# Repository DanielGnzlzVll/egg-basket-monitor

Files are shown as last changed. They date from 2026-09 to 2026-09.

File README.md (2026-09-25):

# Egg Basket Monitor

Sensor de nivel para una canasta de huevos de cocina. Se cuelga del borde,
mide la distancia hasta los huevos con un sensor de tiempo de vuelo
(**VL53L0X**, módulo TOF200C), duerme casi todo el tiempo en un **ESP32-C3
SuperMini** a batería y manda una lectura por hora a **Grafana Cloud**.

El objetivo no es contar huevos, sino avisar con tiempo antes de quedarse en
cero, y hacerlo:

- **sin volcar ni modificar la canasta** — todo cuelga del borde con piezas
  impresas;
- **sin PCB a medida** — módulos comerciales y cables Dupont;
- **sin infraestructura en casa** — el dispositivo habla directo con Grafana
  Cloud, sin broker MQTT ni servidor intermedio;
- **sin credenciales en el código** — WiFi y token se cargan desde un portal
  web que sirve el propio dispositivo.

## Cómo funciona

```
 ┌──────────── deep sleep (60 min por defecto) ◄──────────────┐
 ▼                                                            │
despierta → 20 lecturas ToF → mediana + desviación → batería → WiFi → POST HTTPS
            (sensor encendido     (descarta las        (GPIO3)         a Grafana Cloud
             sólo ~1 s)            inválidas)                          (Influx line protocol)
```

El sensor cuelga de un lado corto de la canasta y apunta **en diagonal** hacia
el fondo, para no tapar la boca. El ángulo se ajusta a mano con una bisagra de
fricción, usando el [modo calibración](docs/calibration.md) para verlo en
vivo. Cuantos más huevos hay, más corta es la distancia medida.

Cada envío es una línea de
[Influx line protocol](https://docs.influxdata.com/influxdb/v2/reference/syntax/line-protocol/):

```
eggbasket,device=cocina distance_mm=412,stddev=1.8,valid=19,status=0,battery_mv=4050,rssi=-52,boots=412
```

| Campo | Qué es |
|---|---|
| `distance_mm` | Mediana de las lecturas válidas del ciclo |
| `stddev` | Desviación estándar de esas lecturas. Si sube de forma sostenida, el ángulo se corrió |
| `valid` | Cuántas de las 20 lecturas fueron válidas |
| `status` | `0` = lectura del ciclo · `1` = lectura reenviada desde el buffer de reintento · `2` = el sensor falló (esa línea no lleva `distance_mm` ni `stddev`) |
| `battery_mv` | Tensión de la celda, leída por el divisor en GPIO3 |
| `rssi` | Señal WiFi en dBm |
| `boots` | Contador de despertares desde el último reset |

Si el envío falla (sin WiFi, error de conexión o del servidor), la muestra
se guarda en la memoria RTC, que sobrevive al deep sleep, con la hora real en
que se midió. En el siguiente envío que funcione se mandan **todas** las
pendientes junto con la actual, en un solo POST y cada una con su hora: un
router reiniciándose no deja huecos en los datos. Entran 48 muestras (dos
días enviando cada hora); si se llena, se descarta la más vieja. Si Grafana
rechaza los datos en sí (HTTP 400, por ejemplo una muestra demasiado vieja),
se descartan en vez de reintentarlos para siempre. El log por serial muestra
las líneas exactas de cada envío. La
calibración distancia → nivel de llenado no vive en el firmware sino en
Grafana, para poder recalibrar sin reflashear.

## Hardware

| Componente | Para qué | Nota |
|---|---|---|
| ESP32-C3 SuperMini | Microcontrolador, WiFi | Número serigrafiado = número de GPIO |
| Módulo ToF **TOF200C (VL53L0X)** | Mide la distancia | **VIN a 3V3, no a 5V.** Ver [abajo](#el-sensor-vl53l0x-no-vl53l1x) |
| TP4056 **con protección** (DW01A + FS8205A), USB-C | Carga la celda y la corta por sobre/subdescarga | La versión sin protección no sirve con una celda desnuda |
| Celda 18650 | Batería, ~4 meses por carga | Nada se suelda a la celda |
| 2 resistencias iguales (1 MΩ) | Divisor para leer la batería | Cualquier par igual sirve |
| Tornillería M3 + M2 con tuercas | Montaje | Sin un solo autorroscante |

Todo por ~USD 8-12 si ya tenés la placa y la celda. Lista completa, con
búsquedas de AliExpress y largos de tornillo, en [`docs/bom.md`](docs/bom.md).

### Conexionado

Esquema de conexionado

| Señal | ESP32-C3 SuperMini | TOF200C |
|---|---|---|
| SDA (I2C) | GPIO4 | SDA |
| SCL (I2C) | GPIO5 | SCL |
| XSHUT (apagado del sensor) | GPIO6 | SHUT |
| Alimentación | 3V3 / GND | VIN / GND |
| Lectura de batería | GPIO3 ← punto medio del divisor | — |

El I2C va en GPIO4/5 y no en los pines por defecto del C3 porque GPIO8 es el
LED RGB de la placa y GPIO9 el botón BOOT.

Cadena de alimentación

Tabla de pines completa, detalles del divisor y el riesgo abierto del
regulador de la placa en [`docs/wiring.md`](docs/wiring.md).

### El sensor: VL53L0X, no VL53L1X

El diseño original pedía un VL53L1X, pero el módulo instalado es un
**TOF200C**, que lleva un **VL53L0X**. Los dos se parecen mucho y contestan
en la misma dirección I2C (`0x29`), así que un escaneo del bus no los
distingue, pero sus registros son incompatibles: el VL53L0X usa direcciones
de 8 bits y el VL53L1X de 16. Con la librería equivocada el escaneo encuentra
el sensor y aun así la inicialización falla siempre. El firmware usa
`pololu/VL53L0X`.

| | VL53L0X (TOF200C, instalado) | VL53L1X (TOF400C) |
|---|---|---|
| Alcance en interior | ~1.2 m (hasta ~2 m con poca luz) | hasta 4 m |
| Cono de visión | 25°, fijo | 27°, reducible con ROI hasta ~15° |
| Identificación | registro `0xC0` = `0xEE` | registro `0x010F` = `0xEACC` |
| Librería | `pololu/VL53L0X` | `pololu/VL53L1X` |

Para una canasta de 50 cm el alcance sobra. La limitación es el cono: sin ROI
no se puede estrechar, y si toca las paredes de la canasta las lecturas salen
más cortas que la distancia real a los huevos. Si pasa, la salida es un
TOF400C, que se conecta igual.

## Piezas impresas

Cinco piezas en PETG (no PLA: la cocina tiene calor y grasa), ninguna
necesita soportes. Toda la tornillería es métrica contra tuerca embutida.

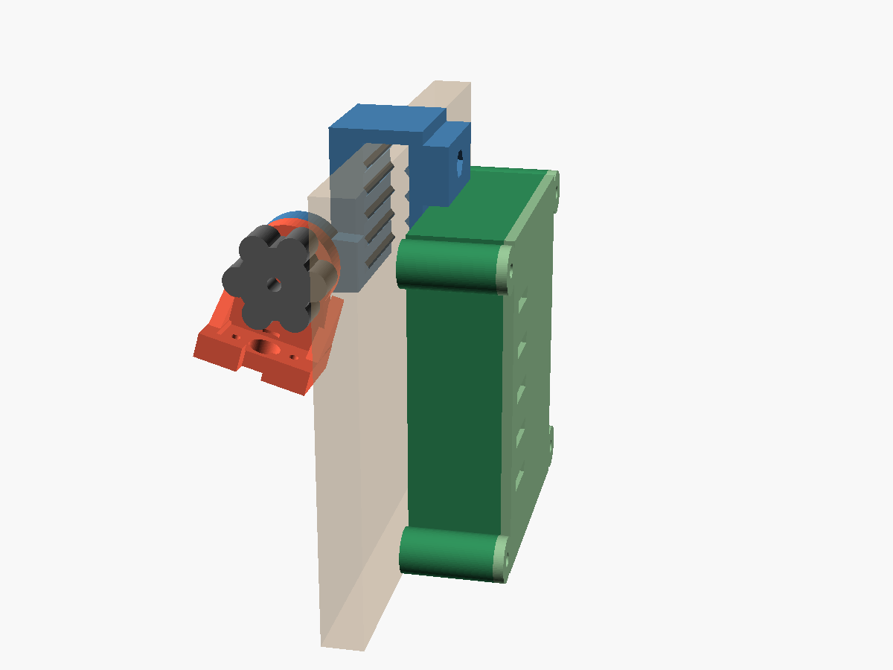
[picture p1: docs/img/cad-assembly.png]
Conjunto colgado del borde de la canasta


*Conjunto colgado del borde (vista aproximada): la cabeza del sensor hacia
dentro de la canasta y la caja de electrónica por fuera, sujetas por el mismo
`mount`; el peso de la caja compensa el brazo del sensor.*

| | |
|---|---|
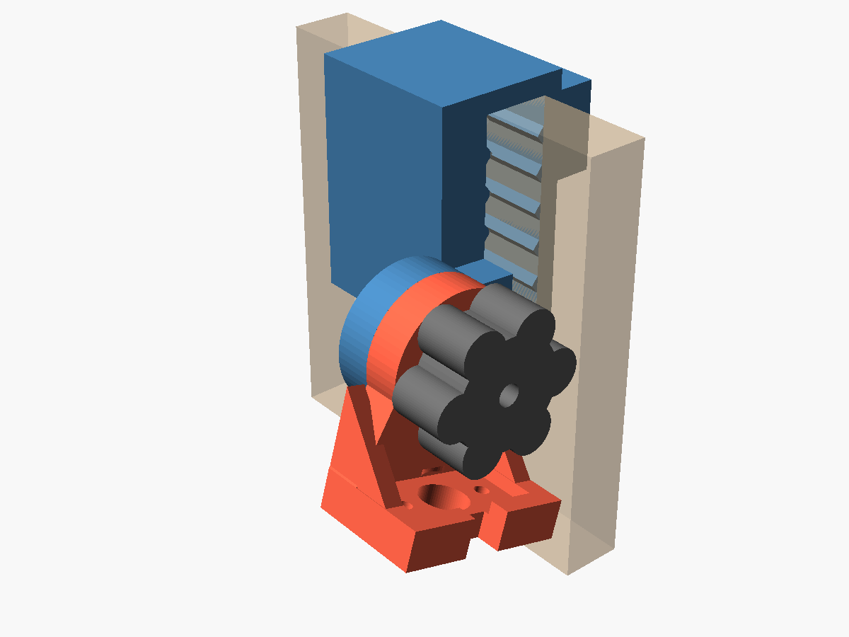
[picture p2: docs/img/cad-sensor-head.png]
Cabeza del sensor
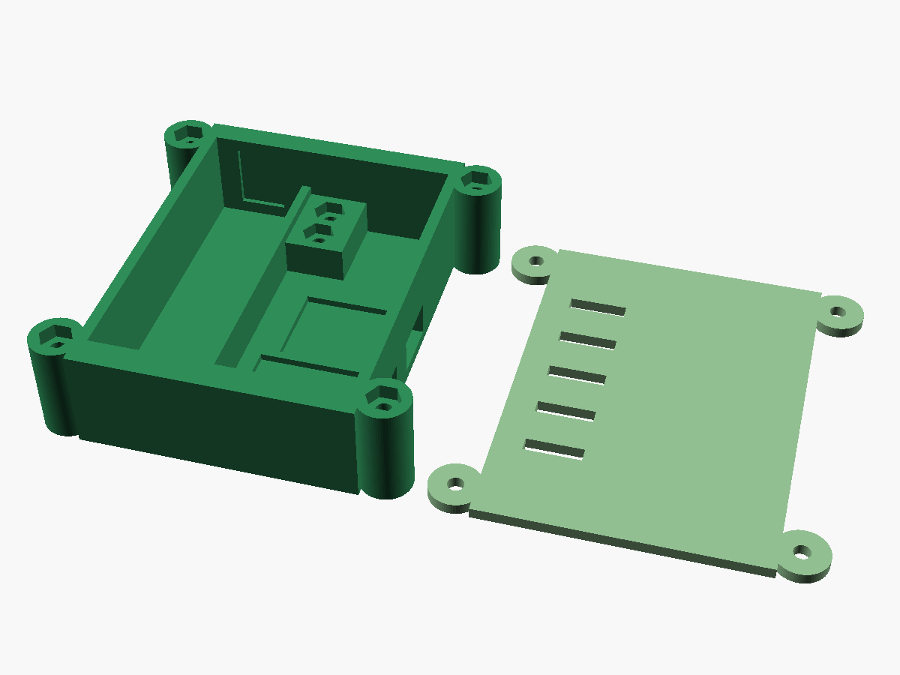
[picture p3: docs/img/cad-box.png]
Caja de electrónica
|  |  |
| **Cabeza del sensor**: `mount` al borde (azul) + `pod` con el bolsillo del TOF200C (rojo) + `knob` de la bisagra de fricción (gris) | **Caja de electrónica**: hueco de la 18650, marcos del TP4056 y el ESP32-C3, espina con las tuercas para el `mount` y la `lid` al lado |

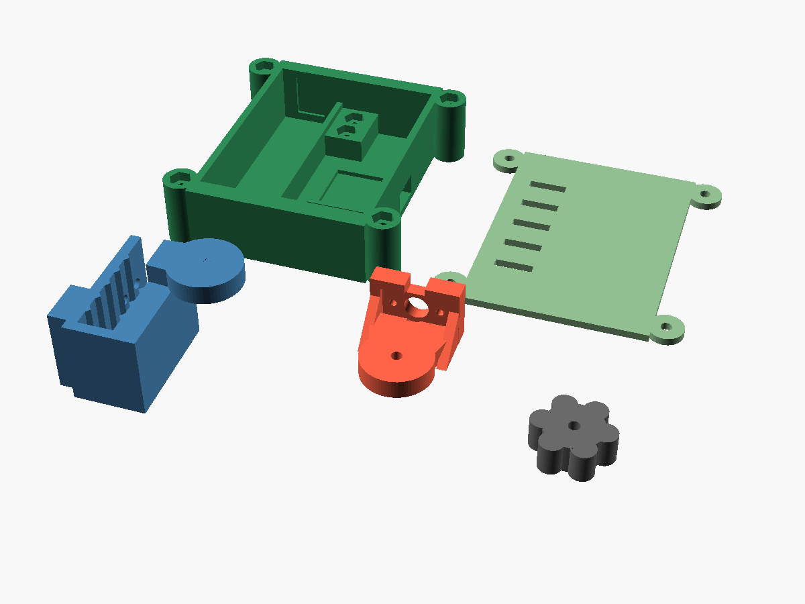
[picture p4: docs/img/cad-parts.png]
Las cinco piezas imprimibles


| Pieza | Qué es | Orientación de impresión |
|---|---|---|
| `mount` | Gancho al borde con un solo punto de apriete, sostiene el pod | De canto |
| `pod` | Alojamiento del TOF200C con la oreja de la bisagra | Oreja hacia arriba |
| `knob` | Pomo de apriete de la bisagra de fricción | Plana |
| `box` | Caja de la electrónica | Boca hacia arriba |
| `lid` | Tapa de la caja | Plana |

Los STL se generan con OpenSCAD:

```
python cad/build.py                 # las cinco piezas, a cad/out/
python cad/build.py pod knob        # sólo esas
python cad/build.py --report        # informe de geometría y tornillería, sin STL
```

Todas las cotas (medidas de la canasta, cono del sensor, tornillería) están
en [`cad/params.scad`](cad/params.scad). `cad/lib/geometry.scad` calcula el
rango de ángulos en el que el cono del sensor llega al fondo sin tocar las
paredes, y aborta la compilación si la canasta no deja ninguno.

**Impresión:** PETG, capa 0.2 mm, 4 perímetros, sin soportes.

## Puesta en marcha

1. **Imprimir y montar** las piezas (arriba) y cablear según el
   [esquema](docs/wiring.md).
2. **Flashear** con [PlatformIO](https://platformio.org/):
   ```
   cd firmware
   pio run -t upload
   pio device monitor      # opcional, para ver los logs
   ```
3. **Configurar.** Recién flasheado, el dispositivo levanta la red WiFi
   **`EggBasket-Setup`** (contraseña `eggbasket2026`, cambiala en
   `firmware/include/config.h` antes de flashear). Conectate desde el celular
   y cargá tu WiFi, la URL de escritura Influx de Grafana Cloud, el Instance
   ID, el token, el nombre del dispositivo y el intervalo de sueño.
4. **Calibrar el ángulo** con la canasta vacía, usando el
   [modo calibración](docs/calibration.md).
5. **Verificar** en Grafana Cloud → Explore → `eggbasket_distance_mm`.

Paso a paso completo, con capturas de lo que sale por serial y qué hacer si
algo falla, en [`docs/setup-tutorial.md`](docs/setup-tutorial.md).

### Botón BOOT y LED

El único botón es el BOOT de la placa. Sostenido **al arrancar** (reset o
conexión de la batería) decide el modo:

| BOOT al arrancar | Modo | LED |
|---|---|---|
| Sin tocar | Ciclo normal: mide, envía, duerme | Verde corto = envío OK · rojo corto = falló, queda para reintentar |
| Sin tocar, **con monitor serie abierto por USB** | Calibración automática | Dos parpadeos verdes |
| 3-8 s | Calibración: 60 s de distancia cruda por serial a 2 Hz | Dos parpadeos verdes |
| Más de 8 s | Portal de configuración `EggBasket-Setup` | Tres parpadeos azules y queda azul fijo |

La calibración automática sólo mira si hay una PC leyendo el puerto serie:
en batería no cuesta nada. Para ver el ciclo normal por serial, poner
`AUTO_CALIBRATION_ON_SERIAL` a `0` en `firmware/include/config.h`.

Tres parpadeos rojos significan batería por debajo de 3.3 V: el dispositivo
entra en sueño indefinido para proteger la celda hasta que se la cargue.

## Autonomía

Con una 18650 de 3000 mAh (2400 mAh utilizables) y un envío por hora:

| Concepto | mAh/día |
|---|---|
| Deep sleep del C3 SuperMini de fábrica (~500 µA) | 12.0 |
| 24 despertares × ~6 s @ ~80 mA | 3.2 |
| TP4056 en reposo + divisor de batería | 1.3 |
| Sensor con XSHUT bajo | ~0.1 * |
| **Total** | **~16.6** |

Unos **4 meses entre cargas**, contando la autodescarga de la celda. El ~90%
del consumo dormido es el LED rojo de power del SuperMini: raspándolo o
desoldándolo, la autonomía sube a **~8.5 meses**. Bajar a dos envíos por día
apenas suma un mes, porque el sueño domina.

\* Calculado para el VL53L1X. El TOF200C trae su propio regulador, cuyo
consumo en reposo no está medido todavía: si resulta alto, ver el plan B
(load switch) en [`docs/bom.md`](docs/bom.md).

## Grafana Cloud

Los datos entran por el endpoint Influx de Grafana Cloud y quedan como series
Prometheus (`eggbasket_distance_mm`, `eggbasket_battery_mv`, …) con el label
`device`. Lo planificado, todavía **pendiente** en el repo:

- **Dashboard** con variables `d_vacia` y `d_llena` para convertir distancia
  en nivel de llenado, más paneles de batería, `stddev`/`valid` y RSSI.
- **Dos alertas a Telegram:** nivel por debajo del 25% durante 2 h
  ("quedan pocos huevos"), y **sin datos durante 36 h** ("el sensor no
  reporta"). La segunda importa tanto como la primera: sin ella, una batería
  agotada es indistinguible de una canasta llena.

El detalle está en la sección "Grafana Cloud" del
[spec de diseño](docs/superpowers/specs/2026-09-04-egg-basket-monitor-design.md).

## Estado del proyecto

- **Firmware:** compila con PlatformIO para el ESP32-C3. El sensor TOF200C
  está verificado en banco, midiendo con el driver del VL53L0X. Falta
  probar el ciclo completo (sensor + WiFi + Grafana) en la placa.
- **CAD:** rediseñado para el TOF200C, con rim mount y bisagra de fricción.
- **Grafana:** dashboard y alertas pendientes.
- **Riesgos abiertos:**
  - El regulador del SuperMini: si es un AMS1117 en vez de uno de baja
    caída, la placa se apaga por debajo de ~4.4 V, con la celda casi llena.
    Se verifica con una fuente variable; ver [`docs/wiring.md`](docs/wiring.md).
  - El cono fijo del VL53L0X contra las paredes de la canasta (ver
    [el sensor](#el-sensor-vl53l0x-no-vl53l1x)).

## Estructura del repo

```
firmware/       Proyecto PlatformIO (ESP32-C3 SuperMini, framework Arduino)
  include/        config.h: pines, tiempos y valores por defecto
  src/            main.cpp (ciclo), sensor, power, telemetry, portal, settings, boot_mode
cad/            Piezas paramétricas en OpenSCAD + build.py para exportar STL
  lib/            Geometría del cono del sensor y gancho al borde
docs/           Cableado, tutorial, calibración, lista de materiales, imágenes
  superpowers/    Specs de diseño y planes de implementación
```

## Documentación

| Documento | Contenido |
|---|---|
| [`docs/setup-tutorial.md`](docs/setup-tutorial.md) | Flasheo, portal de configuración, verificación y problemas comunes |
| [`docs/wiring.md`](docs/wiring.md) | Pinout completo, cadena de alimentación, sensor, botón BOOT |
| [`docs/calibration.md`](docs/calibration.md) | Cómo elegir el ángulo del sensor con el modo calibración |
| [`docs/bom.md`](docs/bom.md) | Lista de materiales, tornillería y piezas impresas |
| [Spec de diseño](docs/superpowers/specs/2026-09-04-egg-basket-monitor-design.md) | Por qué cada decisión, alternativas descartadas, presupuesto energético |
| [Spec del portal WiFi](docs/superpowers/specs/2026-09-17-firmware-wifi-config-design.md) | Provisioning por portal cautivo y guardado en NVS |
| [Spec del rim mount](docs/superpowers/specs/2026-09-18-cad-rim-mount-redesign-design.md) | Rediseño del montaje al borde y bisagra de fricción |

## Licencia

[MIT](LICENSE).

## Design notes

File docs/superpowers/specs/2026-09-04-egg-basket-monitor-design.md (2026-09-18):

# Egg Basket Monitor — Diseño

**Fecha:** 2026-09-04
**Estado:** aprobado, pendiente de plan de implementación

## Problema

Los huevos se acaban sin aviso. Para cuando se nota, ya no hay, y la compra se
pospone otro día. El objetivo es recibir una notificación en Telegram cuando el
nivel de la canasta baje de un umbral, con suficiente antelación para comprar
antes de quedarse en cero.

Requisito secundario, y casi tan importante: el sistema debe avisar cuando *él
mismo* deja de funcionar. Una batería agotada produce exactamente el mismo
silencio que una canasta llena.

## Alcance

Dentro:

- Sensor de nivel montado en la canasta, alimentado por batería.
- Envío periódico a Grafana Cloud sin infraestructura intermedia.
- Dashboard y dos reglas de alerta con notificación a Telegram.
- Piezas imprimibles paramétricas para el sensor y la electrónica.

Fuera:

- PCB a medida. Todo se resuelve con módulos comerciales y cables Dupont.
- Conteo exacto de huevos. Se estima nivel de llenado, no unidades.
- Integración con Home Assistant, listas de compra o pedidos automáticos.
- Multi-canasta. Un solo dispositivo, aunque el esquema de métricas lleva un
  label `device` que lo permitiría después.

## Decisiones de diseño

### Sensado: ToF de zona única

Se evaluaron cuatro alternativas:

| Opción | Descartada porque |
|---|---|
| Barrera IR × 5 niveles | 10 piezas a alinear en una canasta curva, ~10 GPIO, y el haz se cuela entre huevos produciendo falsos vacíos. |
| Sensores de luz ambiente × 5 | Dependen de la iluminación de la cocina, la hora del día y la posición de la canasta. |
| Celda de carga (HX711) | Da conteo real, pero obliga a que la canasta se apoye en una plataforma y sufre deriva del cero a largo plazo. |
| **ToF (elegida)** | Un sensor, un bus, montaje simple, medición independiente de la luz ambiente. |

Dentro de ToF se eligió **VL53L1X** (zona única) sobre VL53L5CX/L8CX (8×8
multizona). El multizona sería técnicamente superior para el montaje diagonal
—devuelve un mapa de profundidad de 64 zonas con 65° de FoV, inmune a los huecos
entre huevos— pero cuesta 3-5× más y es más difícil de conseguir. Se acepta
conscientemente el riesgo de lecturas ruidosas.

**Mitigaciones del ruido, dado que el VL53L1X es un rayo único en diagonal:**

1. 20 lecturas por despertar, se reporta la mediana y la desviación estándar.
   La desviación es un dato de diagnóstico de primera clase: si es alta, el
   ángulo está mal.
2. ROI del receptor reducido para estrechar el cono. El emisor siempre dispara
   27° y eso no es configurable; solo el receptor admite ROI, hasta un mínimo
   de 15° con 4×4 SPADs.
3. Articulación con detentes cada 4° en la pieza impresa, para corregir el
   ángulo sin reimprimir. El ángulo es el parámetro que más probablemente falle
   a la primera. El rango realmente utilizable lo fija la geometría de la
   canasta, no una preferencia: ver la sección siguiente.

### El cono del emisor decide dónde se monta y a cuánto se apunta

Con las medidas reales de la canasta —**300 mm de ancho × 150 mm de fondo ×
500 mm de alto**, borde de ~10 mm— el apuntado deja de ser libre. La canasta es
un pozo profundo y estrecho, y el emisor del VL53L1X dispara un cono fijo de 27°
que no se puede estrechar. Si el cono toca una pared antes de llegar al fondo, la
pared devuelve más señal que los huevos y el sensor mide la pared.

Dos consecuencias, ambas calculadas en `cad/lib/geometry.scad` a partir de las
tres medidas:

- **La mordaza va en mitad de un lado corto**, apuntando a través de los 300 mm.
  Apuntando a través de los 150 mm no hay **ningún** ángulo válido.
- **El rango útil es 8-20°** desde la vertical, cuatro posiciones de detente.
  Por debajo, el borde cercano del ROI ve la pared de montaje; por encima, el
  borde lejano alcanza la pared de enfrente.

El cálculo parte de la posición **real** del sensor, no del borde de la canasta:
el pod cuelga de un brazo que lo mete ~68 mm hacia dentro y ~70 mm hacia abajo.
Eso lo aleja de la pared de montaje, que ayuda, pero lo acerca a la de enfrente,
que es lo que de verdad recorta el rango por arriba. Hacer el cálculo desde el
borde da un máximo de 23,5° que en la práctica no existe.

En el detente nominal de 16° el sensor lee **450 mm con la canasta vacía y
345 mm llena**, unos 104 mm de recorrido útil. Ambas cifras caen dentro del modo
**short** del VL53L1X, que es el más inmune a la luz ambiente: un resultado
afortunado que conviene no perder al tocar cotas.

`geometry.scad` **aborta la compilación** si no queda ningún ángulo válido, o si
queda solo uno (una articulación con una sola posición no regula nada). Cambiar
las medidas de la canasta a algo imposible falla en voz alta en vez de producir
una pieza inútil.

### Montaje: cabeza en el borde, midiendo en diagonal

El sensor se sujeta al borde de la canasta y apunta en diagonal hacia el fondo
opuesto, no verticalmente desde arriba. Esto deja libre la boca de la canasta,
que es por donde se ponen y sacan los huevos.

El sistema se parte en dos cuerpos unidos por un latiguillo Dupont de 20 cm:

- **Cabeza del sensor** (~35 g): mordaza + placa + pod articulado + VL53L1X.
  Cuelga del borde hacia **dentro**.
- **Caja de electrónica** (~90 g con la celda): MCU, 18650, TP4056. Cuelga del
  borde hacia **fuera**, con su propio gancho.

**Corrección respecto a la primera versión de este spec.** Antes decía que la
electrónica no podía ir en el borde porque un 18650 con su cuna pesa ~70 g y
volcaría una canasta liviana. Ese razonamiento medía el peso, que es la
magnitud equivocada: lo que vuelca una canasta es el **momento**, y el momento
depende de dónde cuelga la masa. Colgada por fuera, pegada a la pared, la caja
tiene un brazo de ~12 mm; la cabeza del sensor tiene 45 mm hacia el otro lado.
Los dos momentos son del mismo orden y de signo contrario, así que la caja no
solo no empeora el equilibrio: lo mejora. Un cuerpo suelto en la mesa, además,
obligaba a un latiguillo tenso que es justo lo que tira de la canasta.

Se mantienen los dos motivos por los que la caja no va **dentro**: la celda de
litio no queda suspendida sobre la comida, y la canasta se puede levantar y
lavar soltando dos ganchos. La cara inferior de la caja es plana a propósito,
así que también se sostiene de pie en la mesa si se prefiere.

### La calibración vive en Grafana, no en el firmware

El firmware envía **milímetros crudos**. El mapeo distancia → nivel de huevos se
hace en la query del dashboard con dos variables, `d_vacia` y `d_llena`:

```
nivel_pct = (d_vacia - d) / (d_vacia - d_llena) * 100
```

Recalibrar es editar una variable en el navegador. La alternativa —umbrales en
el firmware— exigiría desmontar la canasta y reflashear cada vez, que es
exactamente lo que va a pasar varias veces durante las primeras semanas.

### Telemetría: POST Influx directo a Grafana Cloud

Grafana Cloud acepta Influx line protocol por HTTP: se toma el endpoint de
Prometheus remote-write y se cambia la ruta a `/api/v1/push/influx/write`
(en algunas regiones el host también cambia `prometheus` por `influx`).
Autenticación Basic con el instance ID como usuario y un token de Access Policy
como contraseña; cuerpo `text/plain`.

Es un POST de una línea de texto. Se descartaron:

- **Prometheus remote_write directo**: requiere protobuf + snappy en el ESP32.
  Mucho código y RAM para el mismo resultado.
- **MQTT → Alloy → Cloud**: exige un equipo siempre encendido en casa.

### Cadencia: 1 envío por hora

El requisito original era 1-2 veces al día. Se sube a una vez por hora porque:

1. **Grafana Cloud es Mimir/Prometheus y una muestra caduca a los 5 minutos.**
   Con 2 muestras al día los paneles y alertas verían "No Data" casi siempre.
   Se resuelve igualmente envolviendo las queries en `last_over_time(...[36h])`,
   pero con datos horarios los dashboards son legibles de verdad.
2. Permite ver *cuándo* se consumen los huevos, no solo cuántos quedan.
3. El costo en batería es aceptable (ver presupuesto energético).

El intervalo es una constante del firmware, fácil de cambiar.

## Hardware

### Plataforma: ESP32-C3 SuperMini

Elegida porque el usuario ya tiene varias unidades y una celda 18650. Las
alternativas evaluadas (FireBeetle 2 ESP32-E con deep sleep de 13 µA y carga
LiPo integrada; FireBeetle 2 ESP32-C6) se descartaron por no aportar nada que
justifique comprar hardware nuevo.

Consecuencias de esta elección, todas resueltas abajo: no tiene cargador de
litio, no tiene divisor de batería, y su deep sleep de fábrica es 30-50× peor
que el de una placa pensada para batería.

### Lista de compras

Ya disponible (costo 0): ESP32-C3 SuperMini, celda 18650, resorte de bolígrafo,
lámina de latón o clip metálico, cable USB-C, filamento PETG.

| # | Componente | Búsqueda en AliExpress | USD |
|---|---|---|---|
| 1 | Módulo VL53L1X, versión 3.3 V pequeña | `VL53L1X module GY-53L1` | 3-6 |
| 2 | TP4056 **con protección**, USB-C | `TP4056 USB-C protection DW01` | 0.60 |
| 3 | Resistencias 1 MΩ 1% (×2) | `1M ohm 1% resistor` | 0.20 |
| 4 | Dupont hembra-hembra 20 cm (pack 40) | `dupont female female 20cm` | 1-2 |
| 5 | Termorretráctil surtido | `heat shrink tube assortment` | 1 |
| 6 | Tornillería M3 + M2 | `M3 hex socket screw assortment kit` | 2-3 |
| | **Total** | | **~8-12** |

La lista completa, con las longitudes exactas de tornillo que calcula el modelo,
vive en `docs/bom.md`. Tres ítems de la primera versión han caído: los **imanes
de neodimio** (la caja ya cuelga del borde con su propio gancho), los
**autorroscantes** (ver abajo) y la **miniprotoboard** (no cabe en el vano de
32 mm, y las dos resistencias del divisor se sueldan en línea sobre un Dupont).

### Tornillería: métrica normal en todas partes

Restricción del usuario, y de las que cambian geometría: tiene M2/M3/M4 de
métrica normal a millares, y **ningún autorroscante**. Así que en el proyecto
no hay ni uno. Donde el tornillo no encuentra nada al otro lado, se embute una
tuerca hexagonal en la pieza impresa y es ella la que hace de rosca; el
hexágono a medida impide que gire, y la pieza pasa a comportarse como si
llevara un inserto roscado.

Sale ganando el diseño, no solo la lista de la compra: una rosca hecha en PLA
se pasa a la tercera o cuarta vez que la aprietas, y estas tres uniones —tapa
de la caja, apriete de los ganchos, módulo del sensor— son justo las que se
van a abrir y cerrar muchas veces durante el montaje y la calibración.

Los tres sitios afectados y lo que costó cada uno:

- **Apriete de los dos ganchos** (`lib/rim_hook.scad`). Tuerca cautiva en la
  cara exterior del saliente. Cambio barato: el saliente ya medía 6 mm.
- **Módulo VL53L1X al pod** (`sensor_head.scad`). El agujero pasa de piloto
  Ø2,1 a pasante Ø2,3 y la tuerca M2 va suelta por detrás del PCB, que es
  también lo que lo aprieta contra el fondo del bolsillo.
- **Tapa de la caja** (`electronics_box.scad`). El caro. Ver abajo.

**Nota sobre el ítem 1:** hay que pedir explícitamente la versión pequeña de
3.3 V. Si el módulo trae un regulador AMS1117 (Iq ~5 mA), consume por sí solo
50× más que todo el resto del circuito en reposo y la batería dura semanas en
vez de meses. Plan B si llega el módulo equivocado: un load switch con MOSFET-P
(~USD 1) para cortarle la alimentación entera durante el sueño.

### Conexionado

Se evitan los pines I²C por defecto del C3 SuperMini: GPIO8 lleva el LED RGB y
es strapping pin, y GPIO9 es el botón BOOT. El ESP32-C3 tiene matriz GPIO libre,
así que I²C se remapea.

| Señal | Pin C3 | Va a |
|---|---|---|
| SDA | GPIO4 | VL53L1X SDA |
| SCL | GPIO5 | VL53L1X SCL |
| XSHUT | GPIO6 | VL53L1X XSHUT (bajo = standby ~5 µA) |
| ADC batería | GPIO3 | Nodo medio del divisor 1M/1M |
| Botón calibración | GPIO9 | Botón BOOT de la placa (pull-up interno) |
| 3V3 / GND | — | VL53L1X VCC / GND |

Cadena de alimentación:

```
18650 → TP4056 (B+/B-)
TP4056 (OUT+/OUT-) → pin 5V del C3 SuperMini → LDO onboard → 3V3
                   → divisor 1M/1M → GPIO3
```

**Riesgo abierto que hay que medir, no asumir:** alimentar el pin 5V con
3.7-4.2 V solo funciona si la placa lleva un LDO de baja caída (ME6211,
SGM2212, ~200 mV de dropout). Si lleva un AMS1117 (1.1 V de dropout), el
sistema muere por debajo de 4.4 V, es decir con la celda casi llena. Se verifica
empíricamente con fuente variable bajando la tensión hasta el brownout. Si
resulta ser AMS1117, la salida es alimentar el pin 3V3 desde un módulo HT7333
(Iq 4 µA) y **no** conectar USB y batería a la vez.

### Presupuesto energético

Con 18650 de 3000 mAh (2400 mAh utilizables), enviando cada hora:

| Concepto | mAh/día |
|---|---|
| Deep sleep del C3 SuperMini de fábrica (~500 µA) | 12.0 |
| 24 despiertos × ~6 s @ ~80 mA | 3.2 |
| VL53L1X en standby con XSHUT bajo | 0.12 |
| TP4056 en reposo + divisor de batería | 1.3 |
| **Total** | **~16.6** |

Eso son ~500 mAh/mes, más ~75 mAh/mes de autodescarga del 18650 → **~4 meses
entre cargas**.

**Optimización opcional:** el ~90% del consumo en deep sleep del C3 SuperMini es
el LED rojo de power. Raspándolo o desoldándolo, el sueño baja a ~100 µA y la
autonomía sube a **~8.5 meses**. Es un paso documentado en el README, no un
requisito.

Bajar a 2 envíos al día ahorra menos de lo que parece (el sueño domina): pasa de
4 a ~5 meses. No compensa perder la resolución temporal.

### Seguridad de la celda de litio

El 18650 es una celda desnuda sin PCM y va a estar en una cocina, descargándose
lentamente durante meses. El momento de mayor riesgo de una celda de litio es
recargarla después de una sobredescarga.

Tres capas, ninguna cara:

1. **TP4056 en su variante con protección** (DW01A + FS8205A): corte por
   sobredescarga (~2.5 V), sobrecarga y cortocircuito.
2. **Corte por software a 3.3 V**: leyendo GPIO3, el firmware entra en deep
   sleep indefinido mucho antes de que el DW01 tenga que actuar.
3. **Cuna impresa con contactos a presión**, sin soldar nunca sobre la celda.

Reglas a documentar en el README: rechazar cualquier celda por debajo de 2.5 V,
nunca cargar una celda hinchada o golpeada, y hacer la primera carga con el
aparato a la vista.

## Diseño 3D

Se usa **OpenSCAD** en lugar de Fusion 360: es texto plano, versionable y
diffeable en un repo público, y se puede editar directamente desde el editor.
Todas las cotas viven en `cad/params.scad`.

> **Actualización 2026-09-18:** `clamp`+`hook` se fusionaron en una sola
> pieza (`mount`) y la bisagra Hirth se reemplazó por un pivote de fricción.
> Las secciones de abajo describen el diseño original; el estado actual vive
> en `docs/superpowers/specs/2026-09-18-cad-rim-mount-redesign-design.md`.

### Cabeza del sensor: cuatro piezas *(implementada)*

`cad/sensor_head.scad` genera las cuatro piezas según la variable `part`. Se
partió en cuatro por una razón concreta: **cada una tiene una orientación de
impresión distinta en la que no necesita ni un solo soporte.** Fundirlas en una
sola pieza obligaría a soportes en la cara dentada, que es justo la que necesita
precisión.

| Pieza | Descripción | Orientación |
|---|---|---|
| `clamp` | Mordaza en C sobre el borde, parametrizada solo por `rim_thickness`. Nervios antideslizantes y tornillo de apriete que rosca directo en el plástico. Pasacables en el puente. | De canto: es un prisma puro, cada capa es el mismo perfil en U |
| `plate` | Placa de bisagra: se atornilla a la cara lateral de la mordaza y lleva la corona Hirth. Aloja la cabeza del perno del pivote en un avellanado. | Plana, dientes hacia arriba |
| `pod` | Brazo con la corona Hirth complementaria en un extremo y el alojamiento del VL53L1X en el otro. Ventana óptica de Ø8 mm, 2 pilotos M2 y dos nervios que refuerzan la unión en T entre el brazo y la pared del PCB. | Plana, dientes hacia arriba |
| `knob` | Pomo lobulado con tuerca M3 embutida. Se afloja a mano, se gira el pod, se aprieta. | Plana |

**La articulación es un acoplamiento Hirth de paso 4°**: dos caras dentadas
idénticas, en cunas radiales, que engranan y se autocentran. Se eligió frente a
un trinquete de pasador y agujeros porque el Hirth es diente-valle continuo, sin
pared entre detentes; con pasadores, la pared entre agujeros a paso fino cae por
debajo del ancho de extrusión y deja de ser imprimible.

El flanco del diente mide `2·π·r·(paso/2)/360`, o sea que se estrecha hacia el
centro: es en el radio interior donde se redondea al imprimir. La primera
versión sacó de ahí la conclusión equivocada —subir `hirth_r_in` para que el
diente interior saliera definido— y eso infló la pieza entera, porque `r_in`
arrastra a `r_out` y `r_out` es el que fija el tamaño.

La regla correcta separa las dos cosas: **`hirth_r_out` manda en el TAMAÑO,
`detent_step` manda en la RESOLUCIÓN, y `hirth_r_in` solo tiene que dejar pasar
la cabeza del tornillo.** Que los dientes interiores salgan redondeados no
importa por dos razones: el par crece con el radio, así que esos dientes apenas
trabajan; y como las dos caras se imprimen con el mismo perfil, se redondean
igual y siguen engranando.

Con `r_out = 17` y paso 4° el flanco exterior mide 0,59 mm, cómodo para una
boquilla de 0,4. Aplicar la regla redujo la placa de 56 × 54 a 37 × 45 mm y el
pod de 52 × 68 a 34 × 46 mm, **sin perder ninguno de los cuatro detentes
válidos**, y de paso bajó la intrusión del sensor dentro de la canasta de 68 a
45 mm.

La corona se construye como un único `polyhedron` y no como la unión de 90
cuñas. No es microoptimización: unir 90 sólidos no convexos en CGAL tardaba más
de cinco minutos y agotaba el timeout; el poliedro tarda quince segundos.

**Las longitudes de tornillería las calcula el modelo y las imprime al
compilar**, para que no se queden obsoletas al tocar una cota. Con las cotas
actuales: pivote M3×12, placa-mordaza 2× M3×30, apriete M3×16 y 2× M2×8 para el
módulo, todos contra tuerca. (Los mínimos calculados son 10,2 / 28,8 / 12,2 /
7,7 mm; se redondean al tamaño comercial siguiente.)

El orden de montaje importa, porque hay piezas que quedan cautivas: las dos
tuercas de la placa y el perno del pivote se colocan **antes** de atornillar la
placa a la mordaza. Una vez montada, la cara de la mordaza tapa la cabeza del
perno y le impide girar, así que el ángulo se cambia solo con el pomo, sin
llaves y sin sujetar nada por detrás.

Tamaños: la pieza mayor es el pod, 34 × 46 × 18 mm. El conjunto pesa ~35 g.

### El gancho al borde es una sola pieza de código

`cad/lib/rim_hook.scad` tiene el perfil en U que se cuelga del borde, y lo usan
tanto la mordaza del sensor como la caja de electrónica. Las dos patas son
parámetros porque cada pieza quiere lo contrario —la cabeza cuelga hacia dentro
y necesita pata interior larga; la caja cuelga hacia fuera y necesita pata
exterior larga— pero el hueco del borde, el apriete y los nervios son
literalmente el mismo código. Cambiar de canasta es tocar `rim_thickness` una
vez y que se arreglen las dos.

### Caja de electrónica: tres piezas *(implementada)*

`cad/electronics_box.scad`. Exterior 77 × 81 × 24 mm, orejas incluidas.

| Pieza | Descripción | Orientación |
|---|---|---|
| `box` | Celda de pie contra una pared; TP4056 y ESP32-C3 tumbados contra el fondo en el vano de al lado, los dos alineados a la derecha para que sus USB-C salgan por el mismo costado. | Boca hacia arriba |
| `lid` | Tapa con ranuras de ventilación sobre la celda. | Plana |
| `hook` | Gancho al borde, con pata exterior larga: es donde se atornilla la caja. | De canto |

Decisiones que no son obvias:

- **Los módulos van tumbados, no de canto.** Así la caja mide 24 mm de fondo en
  vez de 32, y pegada a la pared hace menos palanca. Los ~13 mm que quedan
  libres por delante no se desperdician: son para el cableado Dupont, que
  abulta más que los propios módulos.
- **Nada se suelda a la celda.** El cable se suelda al muelle y a la lámina de
  latón *antes* de montarlos. El muelle además absorbe la variación real de
  longitud: el hueco de 70 mm acepta celdas de 62 a 69 mm, o sea tanto una sin
  proteger de 65 como una con PCB de protección de 69.
- **El tornillo de apriete del gancho va arriba del todo y la caja cuelga por
  debajo.** Si se solaparan, el saliente de 6 mm del tornillo chocaría contra el
  fondo de la caja y esta no apoyaría plana contra la pata.
- **Los cuatro tornillos de la tapa van en orejas exteriores, no en bosses
  interiores.** Es el precio de quitar los autorroscantes, y no era evidente de
  antemano. Una tuerca M3 mide 7,16 mm de esquina a esquina, así que en un boss
  de Ø7,5 no cabe: dejaría 0,17 mm de pared. Agrandarlo a Ø11 tampoco, porque
  el único hueco libre del vano —una vez colocados el TP4056, el MCU y la
  espina— mide 2,75 mm. Con las cuatro orejas fuera la caja pasa de 58 a 77 mm
  de ancho, pero el vano queda entero para los módulos y su cableado, que es
  donde el espacio hacía falta de verdad.
- **La tuerca de cada oreja va embutida por arriba, justo bajo la tapa, y es la
  tapa la que la retiene.** Con la tuerca por abajo harían falta tornillos de
  25 mm que además asomarían por detrás, contra la pared de la canasta. Con
  ella arriba bastan M3×8.

El modelo se autocomprueba con `assert`: que el nicho del muelle no atraviese el
suelo, que ningún módulo pise la espina del gancho ni se salga del suelo, que
ningún hueco de USB caiga a la altura de una oreja y la abra por dentro —la
tuerca se saldría—, y que ningún tornillo del gancho caiga fuera de la pata o
encima del de apriete.

### Piezas pendientes

| Pieza | Descripción |
|---|---|
| `strain_relief.scad` | Pasacables en ambos extremos del latiguillo de 20 cm. |

`cad/build.py` exporta los STL invocando el CLI de OpenSCAD, para que el repo no
guarde binarios generados. Imprime además el informe de geometría y las
longitudes de tornillo, y devuelve código de salida distinto de cero si alguna
pieza falla un `assert`.

**Impresión en Janus (Voron Trident):** PETG —la cocina tiene calor y grasa, el
PLA se deforma—, capa 0.2 mm, 4 perímetros, ~60 g, ~5 h. Diseñado sin soportes:
voladizos por debajo de 45° y la ventana del sensor resuelta con un puente.

⚠️ Janus tiene `[homing_override]` en Z que arranca con `G0 Z10` y cruza la cama
en diagonal. Hay que retirar cualquier pieza alta de la cama antes de lanzar el
print, o el homing estrella el cabezal.

## Firmware

Un solo `src/main.cpp`, sin FreeRTOS ni capas de abstracción. PlatformIO con
framework Arduino; el ESP32-C3 tiene soporte oficial en `platform-espressif32`,
sin necesidad del fork `pioarduino` que sí haría falta con un C6.

Ciclo por despertar (~6 s):

1. Despertar por timer.
2. XSHUT alto, inicializar VL53L1X, aplicar ROI reducido.
3. 20 lecturas → mediana, desviación estándar, conteo de lecturas válidas.
4. XSHUT bajo.
5. Leer batería en GPIO3. Si < 3.3 V → deep sleep indefinido.
6. Conectar WiFi, un POST HTTPS, desconectar.
7. Deep sleep.

Detalles:

- **Secretos fuera del repo.** `include/secrets.h` en `.gitignore`, con
  `include/secrets.h.example` commiteado. El repo es público: credenciales de
  WiFi y token de Grafana no pueden estar en el código.
- **Buffer de reintento en RTC slow memory.** Si falla el WiFi, la muestra se
  guarda con timestamp y se envía en el siguiente POST. Influx line protocol
  acepta timestamp explícito, así que un router reiniciándose no pierde datos.
  Esto también cubre la antena cerámica floja del C3 SuperMini, un defecto
  conocido de esas placas.
- **Modo calibración.** Botón BOOT presionado durante el arranque → 60 s
  imprimiendo distancia por serial a 2 Hz, para elegir el detente en vivo.
- Librería `pololu/VL53L1X` (soporta ROI y es ligera).

Línea enviada:

```
eggbasket,device=cocina distance_mm=142,stddev=3.1,valid=18,status=0,battery_mv=3912,rssi=-58,boots=412
```

`stddev`, `valid` y `status` no son adorno: son la señal de que el ángulo del
sensor está mal antes de que los datos de nivel se vuelvan basura.

## Grafana Cloud

**Datasource:** el Prometheus de la stack. Los datos entran por Influx y se
almacenan como series Prometheus con un label `__proxy_source__="influx"`
añadido automáticamente.

**Dashboard** (`grafana/dashboard.json`), con variables `d_vacia` y `d_llena`:

- Stat "Huevos estimados" — nivel calculado, con umbrales de color.
- Time series de distancia, escala invertida (más arriba = más huevos).
- Stat de batería en mV con umbral en 3.4 V.
- Time series de `stddev` y `valid` — salud de la medición.
- Time series de RSSI.

Todas las queries envueltas en `last_over_time(...[36h])` por la caducidad de
5 minutos de Prometheus.

**Dos reglas de alerta** (`grafana/alert-rules.yaml`), ambas a un contact point
de Telegram:

1. `nivel_pct < 25` sostenido durante 2 h → "Quedan pocos huevos".
   El `for: 2h` evita que una lectura mala dispare la alerta.
2. **No Data durante 36 h** → "El sensor de huevos no reporta".
   Sin esta segunda regla, una batería agotada es indistinguible de una canasta
   llena. Es el modo de fallo más probable del proyecto y el más silencioso.

## Estructura del repo

```
~/git/egg-basket-monitor/          público, MIT
├── README.md
├── LICENSE
├── .gitignore
├── firmware/
│   ├── platformio.ini
│   ├── include/secrets.h.example
│   └── src/main.cpp
├── cad/
│   ├── params.scad
│   ├── sensor_head.scad
│   ├── electronics_box.scad
│   ├── lib/geometry.scad
│   ├── lib/hirth.scad
│   ├── lib/rim_hook.scad
│   ├── strain_relief.scad
│   └── build.py
├── grafana/
│   ├── dashboard.json
│   └── alert-rules.yaml
└── docs/
    ├── bom.md
    ├── wiring.md
    ├── calibration.md
    └── superpowers/specs/
```

## Riesgos abiertos

| Riesgo | Impacto | Cómo se resuelve |
|---|---|---|
| El LDO del C3 SuperMini es un AMS1117 | El sistema muere con la celda al 70% | Medir el brownout con fuente variable. Salida: alimentar 3V3 desde un HT7333. |
| El módulo VL53L1X llega con AMS1117 | Autonomía de semanas en vez de meses | Load switch con MOSFET-P (~USD 1). |
| El ángulo diagonal da lecturas erráticas | El nivel estimado no sirve | Cuatro detentes (8-20°) + `stddev` como métrica de diagnóstico. Última salida: subir a VL53L5CX. |
| Solo hay 12° de ventana angular válida | Un error de montaje de 1 cm en la altura de la mordaza puede sacar al sensor del rango | Verificar con el modo de calibración por serial antes de dar por buena la posición. `geometry.scad` recalcula la ventana si se mide la canasta con más cuidado. |
| Retención del free tier de Grafana Cloud | Histórico corto | Verificar el límite vigente al configurar la stack. |

## Criterios de éxito

1. El dispositivo reporta a Grafana Cloud cada hora durante 7 días seguidos sin
   intervención.
2. La distancia reportada distingue de forma repetible al menos 4 niveles de
   llenado entre canasta vacía y llena.
3. Llega una notificación a Telegram al cruzar el umbral hacia abajo.
4. Llega una notificación a Telegram si el dispositivo se apaga 36 h.
5. Todas las piezas se imprimen sin soportes y se ensamblan sin soldar sobre la
   celda.

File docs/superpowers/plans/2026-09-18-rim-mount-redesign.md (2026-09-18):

# Rim Mount Redesign Implementation Plan

> **For agentic workers:** REQUIRED SUB-SKILL: Use superpowers:subagent-driven-development (recommended) or superpowers:executing-plans to implement this plan task-by-task. Steps use checkbox (`- [ ]`) syntax for tracking.

**Goal:** Fusionar `clamp`+`hook` en una pieza `mount` con un solo punto de apriete al borde, reemplazar la bisagra Hirth por un pivote de fricción, y corregir las cotas del PCB al sensor TOF200C real, sin tocar la geometría de `box`/`lid` ya impresas.

**Architecture:** Todo el proyecto es OpenSCAD paramétrico. `params.scad` es la única fuente de cotas; `lib/geometry.scad` valida el apuntado; `lib/rim_hook.scad` es el perfil en U compartido. Este plan añade `cad/rim_mount.scad` (pieza `mount`), recorta `sensor_head.scad` (pierde `clamp`/`plate`, `pod` cambia de bisagra) y `electronics_box.scad` (pierde `hook`), y borra `lib/hirth.scad`.

**Tech Stack:** OpenSCAD (CLI en `C:\Program Files\OpenSCAD\openscad.exe`), `cad/build.py` (Python, exporta STL y corre los `echo`/`assert` de cada modelo).

**Spec:** `docs/superpowers/specs/2026-09-18-cad-rim-mount-redesign-design.md`

## Global Constraints

- Ni un tornillo autorroscante en todo el proyecto: donde no hay nada al otro lado, tuerca hexagonal embutida.
- Toda cota vive en `params.scad`; ningún otro archivo tiene números mágicos nuevos.
- `box`/`lid` (en `electronics_box.scad`) no cambian ni una cota ni una posición de agujero: ya están impresas.
- Cada pieza se imprime sin soportes (regla del proyecto desde el spec de 2026-09-04).
- Verificación de cada tarea: `python cad/build.py <parte>` debe salir con código 0 y sin `WARNING`/`ERROR`/`ASSERT` en la salida.

---

### Task 1: Corregir cotas del PCB y preparar `params.scad` para la bisagra de fricción

**Files:**
- Modify: `cad/params.scad`

**Interfaces:**
- Produces: `pcb_l = 20.0`, `pcb_hole_spacing = 14.4` (consumidos por `sensor_head.scad` Task 2).
- Produces: nuevos parámetros `hinge_screw_d`, `hinge_ear_w`, `hinge_ear_t`, `hinge_washer_d`, `hinge_arm_t` (consumidos por `sensor_head.scad` Task 2 y `rim_mount.scad` Task 3).
- Produces: `pod_arm` recalculado sin depender de `hirth_r_out` (consumido por `lib/geometry.scad`, sin cambios en ese archivo).
- Produces: bloque `box_iface_*` con la interfaz congelada hacia la caja ya impresa (consumido por `rim_mount.scad` Task 3).
- Removes: `hirth_r_in`, `hirth_r_out`, `hirth_h`, `hirth_backing`, `detent_step`, `plate_t`, `plate_w`, `plate_screw_d`, `plate_screw_sep`. Nadie más los usa tras este plan (confirmado por `grep -rn hirth cad/` antes de empezar: solo aparecían en `params.scad`, `sensor_head.scad` y `lib/hirth.scad`).

- [ ] **Step 1: Corregir las cotas del PCB real (TOF200C)**

En `cad/params.scad`, dentro de `/* [Modulo VL53L1X] */`:

```openscad
pcb_l            = 20.0;  // mm, ancho real del TOF200C (antes 25.0, generico)
pcb_w            = 11.0;  // mm, alto del PCB (ya coincidia)
pcb_t            = 1.6;   // mm, espesor del PCB (sin medir, se mantiene)
pcb_hole_spacing = 14.4;  // mm entre centros de agujero, medido en la ficha del TOF200C (antes 20.0)
pcb_hole_d       = 2.3;   // mm, M2 pasante (el agujero real mide Ø2, esto ya da holgura)
```

- [ ] **Step 2: Verificar que las asserts de `sensor_head.scad` siguen pasando con las cotas nuevas**

Run: `cd cad && python build.py --report`
Expected: en el bloque `--- Modulo VL53L1X ---`, "Con 20 x 11 mm el PCB apoya sobre 2.15 mm de reborde" (el margen no cambia, solo cambió `pcb_l`, que no entra en esa cuenta) y ningún `ERROR`/`ASSERT` en stderr.

- [ ] **Step 3: Reemplazar la sección `[Articulacion Hirth]` por `[Bisagra de friccion]`**

Borrar el bloque completo:
```openscad
detent_step   = 4;
hirth_r_in    = 11;
hirth_r_out   = 17;
hirth_h       = 1.4;
hirth_backing = 3.2;
pivot_screw_d = 3.4;
```

Y en su lugar escribir:
```openscad
/* [Bisagra de friccion] ---------------------------------------------------
   Reemplaza a la articulacion Hirth: una oreja plana en el mount y otra en
   el pod, un tornillo M3 pasante con una arandela entre las caras de
   contacto, apretado a mano con el pomo lobulado. Sin detentes: el angulo
   se fija por friccion pura. Recalibrar en Grafana tras tocar el pivote.    */

hinge_screw_d  = 3.4;   // mm, M3 pasante del pivote
hinge_ear_w    = 22;    // mm, ancho x alto de cada oreja (mount y pod)
hinge_ear_t    = 5;     // mm, espesor de cada oreja
hinge_arm_t    = 5;     // mm, espesor del brazo que conecta la pata del
                        // mount con la oreja (mismo grosor que la oreja)
hinge_washer_d = 7;     // mm, diametro de apoyo de la arandela M3 entre
                        // las dos orejas
```

- [ ] **Step 4: Quitar la sección `[Placa de bisagra]` (ya no existe placa separada)**

Borrar:
```openscad
plate_t          = 6.0;
plate_w          = 18;
plate_screw_d    = 3.4;
plate_screw_sep  = 16;
```

`pivot_drop` se queda (sigue siendo "mm del borde al eje del pivote", ahora del mount en vez de la placa). Dejar el comentario del bloque actualizado a:
```openscad
/* [Pivote] ---------------------------------------------------------------
   pivot_drop: mm del borde de la canasta al eje de la bisagra de friccion.  */

pivot_drop = 28;
```

- [ ] **Step 5: Recalcular `pod_arm` sin el radio del Hirth**

En `/* [Alcance del brazo] */`, cambiar:
```openscad
pod_arm = hirth_r_out + pcb_w / 2 + 6;   // mm
```
por:
```openscad
// Del eje del pivote al centro del sensor: lo justo para que la pared del
// PCB libre la oreja de la bisagra de friccion.
pod_arm = hinge_ear_w / 2 + pcb_w / 2 + 6;   // mm
```

- [ ] **Step 6: Añadir el bloque de interfaz congelada hacia la caja de electrónica**

Al final de `params.scad`, después de la sección `[Caja de electronica]`:

```openscad
/* [Interfaz congelada con la caja de electronica] -------------------------
   La caja (electronics_box.scad: box/lid) YA ESTA IMPRESA. Estos numeros son
   una copia exacta de las cotas con las que se taladro esa pieza fisica; NO
   se recalculan a partir de otros parametros porque el objeto real ya no
   cambia. Los usa rim_mount.scad para que el brazo exterior del mount
   reproduzca el mismo gancho que antes generaba electronics_box.scad.
   Si algun dia se reimprime la caja con otras cotas, hay que actualizar
   este bloque a mano (y solo a mano: no hay formula que lo haga por vos).   */

box_iface_w        = 26;        // = box_hook_w
box_iface_out      = 40;        // = box_hook_out
box_iface_in       = 18;        // = box_hook_in
box_iface_pad      = 3.2;       // = box_hook_pad
box_iface_screw_z  = -7;        // = box_hook_screw_z
box_iface_screw_d  = 3.4;       // = box_screw_d
box_iface_hole_z   = [-26, -34]; // = -(box_hang_drop + out_h - y), y en [71, 63]
                                 // con box_hang_drop=16 y out_h=81 (cell_l=68)
```

- [ ] **Step 7: Verificar que el reporte completo sigue sano**

Run: `cd cad && python build.py --report`
Expected: código de salida 0, sin `ERROR`/`ASSERT`/`WARNING` nuevos. (Fallará al intentar exportar `clamp`/`plate`/`hook` en el Step siguiente porque esos módulos todavía existen pero sus archivos ya no compilarán con los símbolos borrados — eso se resuelve en las Tasks 2 y 4, no antes.)

- [ ] **Step 8: Commit**

```bash
git add cad/params.scad
git commit -m "cad: cotas reales del TOF200C y parametros de la bisagra de friccion"
```

---

### Task 2: Reescribir `pod()` en `sensor_head.scad` con oreja de fricción, quitar `clamp`/`plate`/Hirth

**Files:**
- Modify: `cad/sensor_head.scad`

**Interfaces:**
- Consumes: `hinge_screw_d`, `hinge_ear_w`, `hinge_ear_t` de `params.scad` (Task 1).
- Produces: módulo `pod()` con una oreja plana (agujero `hinge_screw_d`) en el extremo del brazo, sin disco Hirth. `part = "pod" | "knob" | "assembly"` (ya no acepta `"clamp"` ni `"plate"`).
- Removes: módulos `clamp()`, `plate()`, `include <lib/hirth.scad>`, y las variables derivadas que solo ellos usaban (`slot`, `y_plate0`, `y_teeth`, `mount_gx`, `mount_gz`, `mount_lx`, `mount_ly`, `tight_gz`, `boss_t`, `head_cbore_d`, `head_cbore`, `pivot_seat`, `pivot_nut`, `pivot_len`, `mount_len`, `tight_len`).

- [ ] **Step 1: Quitar el include de Hirth y las piezas que desaparecen**

En `cad/sensor_head.scad`, quitar la línea:
```openscad
use     <lib/hirth.scad>
```

Quitar los módulos `clamp()` y `plate()` completos.

- [ ] **Step 2: Simplificar las cotas derivadas al principio del archivo**

Reemplazar el bloque de "Cotas derivadas" (que hoy calcula `slot`, `pad`, `mount_gx`, etc. para el clamp/plate) por solo lo que `pod()` y `knob()` siguen necesitando:

```openscad
// --- Cotas derivadas -------------------------------------------------------
px = rim_thickness + pod_reach;   // X del eje del pivote (global, para la vista)
pz = -pivot_drop;                 // Z del eje del pivote (global, para la vista)

y_pod  = 0;   // el pod ya no se apoya sobre una placa: su cara de la oreja
              // queda al ras de la oreja del mount (ver rim_mount.scad)

wall_t = 6;   // espesor de la pared que sujeta el PCB
eps    = 0.01;

rib_t = 3.0;  // nervios brazo-pared del pod
rib_h = 12;
rib_l = 12;
```

- [ ] **Step 3: Reescribir `pod()` con oreja de fricción en vez de disco Hirth**

```openscad
// ===========================================================================
//  POD DEL SENSOR   (frame local: origen en el eje del pivote, oreja hacia
//                    -X (apoya contra la oreja del mount), apuntado = -Y)
// ===========================================================================

module pod() {
    pocket_l = pcb_l + 2 * pcb_pocket_clear;
    pocket_w = pcb_w + 2 * pcb_pocket_clear;
    body_h   = pocket_w + 2 * clamp_wall;

    difference() {
        union() {
            // Oreja de la bisagra: un bloque plano con el agujero del
            // pivote, del mismo tamano que la oreja complementaria del
            // mount (hinge_ear_w x hinge_ear_w x hinge_ear_t).
            translate([-hinge_ear_t, -hinge_ear_w / 2, -hinge_ear_w / 2])
                cube([hinge_ear_t, hinge_ear_w, hinge_ear_w]);

            // brazo, en el plano de la oreja
            translate([-hinge_ear_t, 0, -wall_t / 2])
                rotate([0, 0, 0])
                linear_extrude(wall_t, convexity = 4)
                    hull() {
                        translate([0, 0]) circle(d = hinge_ear_w * 0.9);
                        translate([-pod_arm + wall_t / 2, 0])
                            square([wall_t, pocket_l + 2 * clamp_wall],
                                   center = true);
                    }

            // pared que sostiene el PCB, perpendicular al apuntado
            translate([-pod_arm + wall_t / 2, -(pocket_l + 2 * clamp_wall) / 2,
                       -body_h / 2])
                cube([wall_t, pocket_l + 2 * clamp_wall, body_h]);

            // Dos nervios de refuerzo brazo-pared.
            for (s = [-1, 1])
                translate([-pod_arm + wall_t, s * (pocket_l + clamp_wall) / 2,
                           -body_h / 2])
                    rotate([0, 90, 90])
                        linear_extrude(rib_t, center = true)
                            polygon([[0, 0], [-rib_h, 0], [0, rib_l]]);
        }

        // Agujero del pivote en la oreja.
        translate([-hinge_ear_t - eps, 0, 0])
            rotate([0, 90, 0]) cylinder(d = hinge_screw_d, h = hinge_ear_t + 2 * eps);

        // Bolsillo del PCB, abierto por la cara trasera (+X local).
        translate([-pod_arm + wall_t - (pcb_t + pcb_pocket_clear),
                   -pocket_l / 2, -pocket_w / 2])
            cube([pcb_t + pcb_pocket_clear + eps, pocket_l, pocket_w]);

        // Ventana optica: atraviesa la pared en la direccion de apuntado.
        translate([-pod_arm - 1, 0, 0])
            rotate([0, 90, 0]) cylinder(d = window_d, h = wall_t + 2);

        // Pasantes M2 para el modulo.
        for (s = [-1, 1])
            translate([-pod_arm - 1, s * pcb_hole_spacing / 2, 0])
                rotate([0, 90, 0]) cylinder(d = pcb_hole_d, h = wall_t + 2);

        // Salida de los Dupont por arriba.
        translate([-pod_arm + wall_t / 2, 0, body_h / 2 - 3])
            cube([wall_t + 2, wire_channel_d, 6], center = true);
    }
}
```

> Nota para quien ejecute este paso: la reescritura cambia el eje de
> apuntado de "apoyado sobre un plano XY con dientes hacia +Z" a "un
> bloque simple con el eje del pivote en X". Es MUY probable que al
> renderizar por primera vez algo quede desalineado (ventana optica no
> centrada en la pared, bolsillo del PCB en el lado equivocado, nervios
> chocando con el bolsillo). Eso se corrige en el Step 5 mirando el PNG,
> no adivinando: no hay manera de garantizar en el papel que una
> reescritura de este tamano salga perfecta a la primera.

- [ ] **Step 4: Actualizar la selección de pieza al final del archivo**

```openscad
if      (part == "pod")      pod();
else if (part == "knob")     knob();
else if (part == "assembly") assembly();
else assert(false, str("part desconocida: ", part));
```

Y simplificar `assembly()` para que ya no posicione `clamp()`/`plate()` (se mueve a `rim_mount.scad`, Task 3 lo re-arma):

```openscad
module assembly() {
    basket_context();
    color("Crimson") translate([px, 0, pz]) pod();
    color("DimGray") translate([px - hinge_ear_t - 1, 0, pz]) rotate([0, -90, 0]) knob();
}
```

- [ ] **Step 5: Compilar, mirar el render y corregir lo que no cuadre**

Run:
```bash
cd cad
python build.py pod knob
"C:\Program Files\OpenSCAD\openscad.exe" -o out/pod_preview.png --imgsize=1000,800 --camera=0,0,0,55,0,25,150 -D 'part="pod"' sensor_head.scad
```

Leer `cad/out/pod_preview.png` con la herramienta Read y confirmar: la ventana óptica cae centrada en la pared, el bolsillo del PCB no atraviesa la oreja, los nervios no invaden el bolsillo ni la ventana, y no queda ningún hueco flotante (geometría no manifold). Si algo no cuadra, ajustar las coordenadas del Step 3 y repetir — no seguir a la Task 3 hasta que este render se vea correcto.

Expected: `python build.py pod knob` sale con código 0 y sin `ERROR`/`ASSERT` en stderr; el PNG muestra un brazo sólido con ventana óptica centrada.

- [ ] **Step 6: Commit**

```bash
git add cad/sensor_head.scad
git commit -m "cad: pod con oreja de friccion, elimina clamp/plate/hirth de sensor_head"
```

---

### Task 3: Crear `cad/rim_mount.scad` con la pieza combinada `mount`

**Files:**
- Create: `cad/rim_mount.scad`

**Interfaces:**
- Consumes: `hook_slot`, `hook_boss`, `rim_hook()`, `rim_hook_screw_len()` de `lib/rim_hook.scad`; `clamp_width`, `clamp_wall`, `clamp_grip_in`, `grip_ribs`, `pivot_drop`, `hinge_screw_d`, `hinge_ear_w`, `hinge_ear_t`, `hinge_arm_t`, `pod_reach`, `rim_thickness`, `box_iface_*`, `nut_h` de `params.scad`.
- Produces: módulo `mount()`, seleccionable con `part = "mount"`.

- [ ] **Step 1: Escribir `cad/rim_mount.scad`**

```openscad
// ===========================================================================
//  egg-basket-monitor  ::  mount unificado (mordaza + gancho)
//
//  Una sola pieza que se aprieta al borde de la canasta en un UNICO punto y
//  sostiene dos cosas a la vez:
//    - brazo interior: termina en una oreja de friccion donde se atornilla
//      el pod del sensor (reemplaza a clamp + plate + Hirth).
//    - brazo exterior: reproduce la interfaz de montaje que YA tiene la
//      caja de electronica impresa, cotas congeladas en params.scad
//      (reemplaza al modulo hook() de electronics_box.scad).
//
//  Se imprime de canto, igual que antes: prisma puro, sin soportes.
//
//  Uso:  openscad -D 'part="mount"' -o mount.stl rim_mount.scad
// ===========================================================================

include <lib/geometry.scad>    // arrastra params.scad y valida el apuntado
include <lib/rim_hook.scad>    // perfil en U compartido

part = "mount";

// --- Cotas derivadas -------------------------------------------------------
pad = 8;   // espesor de la pata interior, donde nace el brazo de la oreja

// Un solo tornillo de apriete al borde para todo el conjunto, arriba del
// todo (igual que el hook original) para que su saliente no choque contra
// la caja colgada por debajo.
tight_gz = box_iface_screw_z;

// Eje del pivote, mismo punto que usan sensor_head.scad y geometry.scad.
px = rim_thickness + pod_reach;
pz = -pivot_drop;

tight_len = rim_hook_screw_len();
hinge_len = 2 * hinge_ear_t + 3 + nut_h;   // dos orejas + arandela + tuerca

echo(str("--- Tornilleria mount --------------------------------------"));
echo(str("  Apriete al borde  M3 x ", round(tight_len * 10) / 10,
         " mm + 1 tuerca (cautiva en el saliente)"));
echo(str("  Pivote (bisagra)  M3 x ", round(hinge_len * 10) / 10,
         " mm + 1 tuerca (pomo) + 1 arandela suelta"));
echo(str("=========================================================="));

module mount() {
    union() {
        difference() {
            // Cuerpo base: pata interior larga (clamp_grip_in, para la
            // sensor) + pata exterior larga (box_iface_out, para la caja),
            // ambas en el MISMO punto de apriete.
            rim_hook(clamp_width, box_iface_out, clamp_grip_in, pad, tight_gz,
                     ribs = grip_ribs);

            // Pasantes hacia la espina de la caja (interfaz congelada).
            for (z = box_iface_hole_z)
                translate([-clamp_wall - 1, 0, z])
                    rotate([0, 90, 0])
                        cylinder(d = box_iface_screw_d, h = clamp_wall + 2);
        }

        // Brazo hacia la oreja de la bisagra: de la pata interior hasta el
        // eje del pivote.
        hull() {
            translate([hook_slot + pad / 2, 0, -clamp_grip_in / 2])
                cube([hinge_arm_t, hinge_ear_w * 0.6, hinge_ear_w * 0.6],
                     center = true);
            translate([px, 0, pz])
                cube([hinge_arm_t, hinge_ear_w, hinge_ear_w], center = true);
        }

        // Oreja de la bisagra, con el agujero del pivote.
        difference() {
            translate([px - hinge_ear_t / 2, 0, pz])
                cube([hinge_ear_t, hinge_ear_w, hinge_ear_w], center = true);
            translate([px, 0, pz])
                rotate([0, 90, 0]) cylinder(d = hinge_screw_d, h = hinge_ear_t + 2,
                                            center = true);
        }
    }
}

if (part == "mount") mount();
else assert(false, str("part desconocida: ", part));
```

- [ ] **Step 2: Compilar y revisar el reporte de tornillería**

Run:
```bash
cd cad
"C:\Program Files\OpenSCAD\openscad.exe" -D 'part="mount"' -o out/mount.stl rim_mount.scad
```
Expected: código de salida 0, `out/mount.stl` generado, sin `ERROR`/`WARNING` de geometría no-manifold en stderr.

- [ ] **Step 3: Renderizar y verificar visualmente**

Run:
```bash
"C:\Program Files\OpenSCAD\openscad.exe" -o out/mount_preview.png --imgsize=1000,800 --camera=0,0,-20,55,0,25,200 -D 'part="mount"' rim_mount.scad
```
Leer `cad/out/mount_preview.png` con Read y confirmar: la pata interior y exterior salen del mismo punto de apriete, el brazo llega limpio hasta la oreja sin huecos ni intersecciones raras, y los dos agujeros hacia la caja quedan dentro del material de la pata exterior (no se salen por el canto). Si el `hull()` del brazo no conecta bien con la pata interior (es fácil que el primer intento deje un hueco porque el punto de partida del hull no toca la superficie real de la pata), ajustar la posición/tamaño del primer bloque del `hull()` hasta que el render se vea sólido, y repetir el render.

- [ ] **Step 4: Renderizar el ensamblaje completo (mount + pod + knob) para chequear que el pivote alinea**

Run:
```bash
"C:\Program Files\OpenSCAD\openscad.exe" -o out/full_assembly.png --imgsize=1200,900 --camera=0,0,-30,55,0,25,250 -D 'part="assembly"' sensor_head.scad
```
Modificar temporalmente `assembly()` en `sensor_head.scad` (o crear un archivo de vista aparte) para que también incluya `mount()` de `rim_mount.scad` vía `use`, y confirmar en el PNG que la oreja del pod y la oreja del mount coinciden en posición y tamaño (mismo `px`, `pz`, mismo `hinge_ear_w`).

Expected: las dos orejas se ven alineadas y del mismo tamaño en el render; si no, el desajuste casi seguro está en que `pod()` usa `-hinge_ear_t/2` como centro de su oreja en X mientras `mount()` la coloca en `px - hinge_ear_t/2` — revisar signos antes de tocar cualquier otra cosa.

- [ ] **Step 5: Commit**

```bash
git add cad/rim_mount.scad
git commit -m "cad: nueva pieza mount, fusiona clamp+hook en un solo punto de apriete"
```

---

### Task 4: Quitar `hook()` de `electronics_box.scad` sin tocar `box()`/`lid()`

**Files:**
- Modify: `cad/electronics_box.scad`

**Interfaces:**
- Consumes: nada nuevo.
- Removes: módulo `hook()`, la parte de `assembly_raw()` que lo dibuja, y `part == "hook"` de la selección final.
- Preserves exactamente: `box()`, `lid()`, y todas las constantes derivadas que ambos usan (`out_w`, `out_h`, `hook_cx`, `hook_hole_y`, `spine_*`, etc. — estas se quedan, porque `box()` las sigue necesitando para taladrar la espina; solo se deja de generar el `hook()` en sí).

- [ ] **Step 1: Quitar el módulo `hook()`**

Borrar el bloque completo:
```openscad
// ===========================================================================
//  GANCHO
// ===========================================================================

module hook() {
    ...
}
```

- [ ] **Step 2: Quitar la parte del gancho en `assembly_raw()`**

Reemplazar:
```openscad
module assembly_raw() {
    color("SteelBlue") box();
    color("Silver")    translate([0, 0, lid_z]) lid();

    // La celda, para ver que cabe.
    color("DimGray", 0.6)
        translate([cx, y0 + 1, cz]) rotate([-90, 0, 0])
            cylinder(d = cell_d, h = in_h - 3);

    // El gancho vive en otro marco ...
    multmatrix(...) {
        color("Goldenrod") hook();
        color("Tan", 0.25) translate(...) cube(...);
    }
}
```
por:
```openscad
module assembly_raw() {
    color("SteelBlue") box();
    color("Silver")    translate([0, 0, lid_z]) lid();

    // La celda, para ver que cabe.
    color("DimGray", 0.6)
        translate([cx, y0 + 1, cz]) rotate([-90, 0, 0])
            cylinder(d = cell_d, h = in_h - 3);
}
```

- [ ] **Step 3: Quitar `"hook"` de la selección de pieza**

```openscad
if      (part == "box")      box();
else if (part == "lid")      lid();
else if (part == "assembly") assembly();
else assert(false, str("part desconocida: ", part));
```

- [ ] **Step 4: Verificar que `box`/`lid` no cambiaron ni un mm**

Run:
```bash
cd cad
python build.py --report 2>&1 | grep -A3 "Caja de electronica"
```
Expected: exactamente igual que antes del cambio — `Exterior: 77.4 x 81 x 24.4 mm (orejas incluidas)`, `Hueco de 70 mm: acepta celdas de 62 a 69 mm`. Si algún número cambió, hay una regresión: revisar el diff, no debería haberse tocado ninguna constante que `box()` usa.

```bash
python build.py box lid
```
Expected: código 0, sin `ERROR`/`ASSERT`.

- [ ] **Step 5: Commit**

```bash
git add cad/electronics_box.scad
git commit -m "cad: quita hook de electronics_box, se muda a rim_mount.scad"
```

---

### Task 5: Actualizar `build.py`, borrar `lib/hirth.scad`, y confirmar el build completo

**Files:**
- Modify: `cad/build.py`
- Delete: `cad/lib/hirth.scad`

**Interfaces:**
- Consumes: nada nuevo.
- Produces: `MODELS` con las 5 piezas finales, `PARTS` derivado igual que antes.

- [ ] **Step 1: Confirmar que nada más usa `lib/hirth.scad`**

Run: `grep -rn "hirth" cad/ --include=*.scad`
Expected: cero resultados (Task 1 y 2 ya quitaron todos los usos).

- [ ] **Step 2: Borrar el archivo**

```bash
git rm cad/lib/hirth.scad
```

- [ ] **Step 3: Actualizar el diccionario `MODELS` en `cad/build.py`**

```python
MODELS = {
    "sensor_head.scad": ["pod", "knob"],
    "electronics_box.scad": ["box", "lid"],
    "rim_mount.scad": ["mount"],
}
```

- [ ] **Step 4: Correr el build completo**

Run: `cd cad && python build.py`
Expected: `5/5 piezas exportadas.`, código de salida 0, y en el reporte de tornillería previo ningún `ERROR`/`ASSERT`.

- [ ] **Step 5: Commit**

```bash
git add cad/build.py
git commit -m "cad: build.py exporta mount en vez de clamp/hook, borra lib/hirth.scad sin uso"
```

---

### Task 6: Actualizar documentación (`docs/bom.md` y nota en el spec de 2026-09-04)

**Files:**
- Modify: `docs/bom.md`
- Modify: `docs/superpowers/specs/2026-09-04-egg-basket-monitor-design.md`

**Interfaces:** ninguna (solo documentación).

- [ ] **Step 1: Actualizar la tabla de tornillería en `docs/bom.md`**

Reemplazar:
```markdown
| Dónde | Tornillo | Tuerca | Cant. |
|---|---|---|---|
| Pivote de la articulación | M3×12 | 1, embutida en el pomo | 1 |
| Placa → mordaza | M3×30 | 2, embutidas en la placa | 2 |
| Apriete de los dos ganchos | M3×16 | 2, cautivas en el saliente | 2 |
| Caja → gancho | M3×14 | 2, embutidas en la espina | 2 |
| Tapa de la caja | M3×8 | 4, cautivas bajo la tapa | 4 |
| Módulo VL53L1X al pod | M2×8 | 2, sueltas por detrás del PCB | 2 |

**Total: 11 tornillos M3, 2 tornillos M2, 11 tuercas M3, 2 tuercas M2.**
```
por (ajustar las longitudes exactas al valor que imprima `python cad/build.py --report` en ese momento, no copiar los números de este plan a ciegas):
```markdown
| Dónde | Tornillo | Tuerca | Cant. |
|---|---|---|---|
| Pivote de la bisagra de fricción | M3×<ver build.py> | 1, en el pomo | 1 + 1 arandela suelta |
| Apriete del mount al borde | M3×<ver build.py> | 1, cautiva en el saliente | 1 |
| Mount → caja (interfaz heredada) | M3×14 | 2, embutidas en la espina de la caja | 2 |
| Tapa de la caja | M3×8 | 4, cautivas bajo la tapa | 4 |
| Módulo VL53L1X al pod | M2×<ver build.py> | 2, sueltas por detrás del PCB | 2 |

**Total: 8 tornillos M3, 2 tornillos M2, 8 tuercas M3, 2 tuercas M2, 1 arandela.**
```

- [ ] **Step 2: Actualizar la tabla de piezas impresas en `docs/bom.md`**

Reemplazar:
```markdown
| Pieza | Orientación |
|---|---|
| `clamp` | De canto |
| `plate` | Plana, dientes hacia arriba |
| `pod` | Plana, dientes hacia arriba |
| `knob` | Plana |
| `box` | Boca hacia arriba |
| `lid` | Plana |
| `hook` | De canto |
```
por:
```markdown
| Pieza | Orientación |
|---|---|
| `mount` | De canto |
| `pod` | (ver nota de orientación en `sensor_head.scad` tras el Task 2) |
| `knob` | Plana |
| `box` | Boca hacia arriba |
| `lid` | Plana |
```

Y actualizar la frase "Siete, ninguna necesita soportes." a "Cinco, ninguna necesita soportes." (confirmar antes que `pod()` reescrito de verdad no necesite soportes con la nueva forma; si el render del Task 2 mostró voladizos >45°, anotarlo aquí en vez de afirmar algo falso).

- [ ] **Step 3: Añadir nota en el spec de 2026-09-04**

En la sección "Diseño 3D" de `docs/superpowers/specs/2026-09-04-egg-basket-monitor-design.md`, justo antes de "### Cabeza del sensor: cuatro piezas *(implementada)*", añadir:

```markdown
> **Actualización 2026-09-18:** `clamp`+`hook` se fusionaron en una sola
> pieza (`mount`) y la bisagra Hirth se reemplazó por un pivote de fricción.
> Las secciones de abajo describen el diseño original; el estado actual vive
> en `docs/superpowers/specs/2026-09-18-cad-rim-mount-redesign-design.md`.
```

- [ ] **Step 4: Commit**

```bash
git add docs/bom.md docs/superpowers/specs/2026-09-04-egg-basket-monitor-design.md
git commit -m "docs: actualiza bom y spec original tras fusionar clamp+hook en mount"
```

---

### Task 7: Verificación final end-to-end

**Files:** ninguno nuevo, solo verificación.

- [ ] **Step 1: Build completo desde cero**

Run: `cd cad && rm -rf out && python build.py`
Expected: `5/5 piezas exportadas.`, código 0.

- [ ] **Step 2: Revisar el reporte de geometría completo una última vez**

Run: `python build.py --report`
Expected: el bloque de `geometry.scad` sigue mostrando `Posiciones utilizables: [8, 12, 16, 20] grados` (no cambió, porque `pod_arm` recalculado con la oreja en vez del Hirth debe seguir dando un valor razonable — si el rango de ángulos válidos se vació o quedó en 1 posición, `geometry.scad` aborta solo y hay que revisar `hinge_ear_w`/`pod_reach` en `params.scad`).

- [ ] **Step 3: Render final del ensamblaje para inspección visual**

Run:
```bash
"C:\Program Files\OpenSCAD\openscad.exe" -o out/final_check.png --imgsize=1400,1000 --camera=0,0,-30,55,0,25,300 -D 'part="assembly"' sensor_head.scad
```
Leer el PNG con Read. Confirmar que se ve un conjunto coherente: mordaza al borde, brazo hacia el pivote, pod apuntando hacia dentro, sin piezas flotantes ni intersecciones visualmente rotas.

- [ ] **Step 4: Reportar al usuario**

Resumir qué cambió, qué archivos se tocaron, y pedir confirmación de que el `mount` puede fabricarse (imprimirse) antes de dar la tarea por cerrada — es la primera vez que esta geometría existe, no hay impresión previa que la valide.

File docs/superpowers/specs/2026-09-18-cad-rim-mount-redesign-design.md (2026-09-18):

# Rediseño de cabeza del sensor: mordaza+gancho unificados, bisagra simple, cotas reales

**Fecha:** 2026-09-18
**Estado:** aprobado, pendiente de plan de implementación

## Problema

Tres cosas no funcionan bien en el diseño 3D actual (`docs/superpowers/specs/2026-09-04-egg-basket-monitor-design.md`):

1. **`clamp` (mordaza del sensor) y `hook` (gancho de la caja) son dos piezas
   independientes** que en la práctica hay que instalar en el mismo punto del
   borde, una agarrando desde dentro y otra desde fuera. Nada en el CAD las
   alinea entre sí: es el instalador quien tiene que acertar la posición a ojo.
2. **La articulación Hirth es más compleja de lo que este proyecto necesita.**
   90 posiciones talladas como un polyhedro para una ventana que solo usa 4.
3. **Las cotas del PCB en `params.scad` no coinciden con el sensor real
   comprado** (TOF200C): `pcb_l` y `pcb_hole_spacing` están mal.

La `box`/`lid` de la caja de electrónica **ya están impresas y quedan
congeladas**: ningún cambio de este documento puede tocar su geometría ni la
posición de sus agujeros.

## Alcance

Dentro:

- Fusionar `clamp` + `hook` en una sola pieza (`mount`) que se aprieta al
  borde en un único punto y sostiene tanto el brazo del sensor como la caja
  ya impresa.
- Reemplazar la bisagra Hirth por un pivote de fricción (tornillo M3 + tuerca,
  sin detentes).
- Corregir `pcb_l` y `pcb_hole_spacing` a las cotas reales del TOF200C.
- Actualizar `cad/build.py`, `docs/bom.md` y la tabla de piezas del spec de
  2026-09-04 para reflejar el nuevo inventario de piezas y tornillería.

Fuera:

- Cualquier cambio a `box`/`lid` (`electronics_box.scad`).
- Cambios al firmware, a Grafana o a la lógica de calibración: `geometry.scad`
  sigue siendo la fuente de verdad del ángulo válido, solo cambia cómo se
  materializa ese ángulo en la pieza impresa.

## Decisiones de diseño

### Pieza combinada `mount`, un solo punto de apriete al borde

Hoy `clamp` y `hook` comparten el perfil en U de `lib/rim_hook.scad` pero son
dos sólidos, dos tornillos de apriete y dos posiciones que deben coincidir por
convención, no por construcción. Se fusionan en una sola pieza `mount` con:

- **El apriete al borde**, una sola vez (antes eran dos tornillos
  independientes, uno por pieza).
- **Un brazo hacia dentro** que termina en una oreja con agujero pasante M3:
  aquí se atornilla el `pod` (ver más abajo). Reemplaza a `clamp` + `plate`.
- **Un brazo hacia fuera** que reproduce *exactamente* la interfaz de
  montaje que ya existe en la `box` impresa: mismas posiciones de agujero,
  mismo diámetro de tornillo. La caja no se entera de que antes colgaba de una
  pieza separada.

Efecto práctico: para levantar la canasta y lavarla se afloja **un tornillo**,
no dos. Y como los dos brazos salen del mismo punto de apriete, el balance de
momento que describía el spec original (la caja hacia fuera compensando el
brazo del sensor hacia dentro) queda garantizado por construcción en vez de
depender de que el instalador ponga las dos piezas en el mismo sitio.

Restricción dura: las cotas de la interfaz hacia la caja (posición de los dos
agujeros, diámetro de tornillo, profundidad de rosca) se toman **tal cual**
de `electronics_box.scad` — no se recalculan, se copian, porque la caja no se
puede reimprimir.

### Bisagra de fricción, sin detentes

Se elimina `lib/hirth.scad` completo (no queda ningún otro consumidor) y el
módulo `plate()` de `sensor_head.scad`. La corona dentada se reemplaza por:

- Una oreja plana en el brazo interior del `mount` (mencionada arriba).
- Una oreja equivalente en el extremo del `pod`, donde antes iba el disco
  Hirth.
- Un tornillo M3 pasante por las dos orejas, con una arandela entre las caras
  de contacto para repartir la presión, y una tuerca (el `knob` actual,
  reutilizado sin cambios de forma) que se aprieta a mano.

Se mantiene tornillo y no filamento como eje: con un tornillo, la fricción se
regula apretando o aflojando, y sigue siendo tornillería métrica normal del
proyecto (ningún ítem nuevo en la lista de compras). El eje de filamento
quedaría fijo sin forma de ajustar cuánto agarra.

**Riesgo aceptado explícitamente por decisión del usuario:** sin detentes, el
ángulo puede correrse con vibración o al apretar de forma distinta cada vez
que se desmonta, y la calibración en Grafana (`d_vacia`/`d_llena`) deja de ser
tan repetible como con el Hirth. Mitigación de bajo costo: se documenta en
`docs/calibration.md` recalibrar cada vez que se toca el pivote, y se
recomienda una arandela de presión (tipo grower) si el usuario tiene una en su
kit de tornillería, para que el apriete no ceda solo con el tiempo.

`pod_arm` (hoy `hirth_r_out + pcb_w / 2 + 6`, en `params.scad`) se recalcula
en función del tamaño de la nueva oreja en vez del radio del Hirth.
`geometry.scad` no cambia: sigue validando el rango de ángulos a partir del
`pod_arm` que le llegue, sea cual sea su origen.

### Cotas reales del TOF200C

En `params.scad`, sección `[Modulo VL53L1X]`:

| Parámetro | Antes | Ahora | Fuente |
|---|---|---|---|
| `pcb_l` | 25.0 | **20.0** | ancho total del PCB en la foto |
| `pcb_hole_spacing` | 20.0 | **14.4** | separación real entre centros de agujero |
| `pcb_w` | 11.0 | sin cambio | ya coincide con el alto real del PCB |
| `pcb_hole_d` | 2.3 | sin cambio | agujero real mide Ø2, 2.3 ya da holgura para M2 |
| `window_d` | 7.5 | sin cambio | ya es el máximo que deja `pcb_support >= 2` con `pcb_w=11`; la ranura óptica real (9.6×5 ovalada) es más ancha de lo que el margen del PCB permite, así que se prioriza que el PCB apoye bien |

Los `assert` existentes en `sensor_head.scad` (separación de agujeros vs.
ventana, agujeros dentro del PCB) se vuelven a evaluar solos con los números
nuevos; si algo deja de cuadrar, la compilación aborta y lo dice.

### Reestructuración de archivos

- **Nuevo `cad/rim_mount.scad`**: genera `mount` (`part="mount"`). Incluye
  `lib/rim_hook.scad` para el perfil de apriete al borde.
- **`sensor_head.scad`**: pierde `clamp`, `plate` y el `use <lib/hirth.scad>`.
  Se queda con `pod` (con oreja de fricción en vez de disco Hirth) y `knob`
  (sin cambios de forma).
- **`electronics_box.scad`**: pierde el módulo `hook`. `box` y `lid` no
  cambian ni una cota. Las constantes que definen la interfaz de montaje hacia
  el gancho (posición de los dos agujeros de la espina, diámetro de tornillo)
  se promueven a `params.scad` para que `rim_mount.scad` las lea de ahí en
  vez de duplicarlas o de tener que importar todo `electronics_box.scad`
  (que tiene sus propios `echo`/`assert` de nivel superior).
- **`lib/hirth.scad`**: se borra. Sin usos tras el cambio.
- **`cad/build.py`**: el diccionario `MODELS` pasa a:
  ```
  "sensor_head.scad":    ["pod", "knob"],
  "electronics_box.scad": ["box", "lid"],
  "rim_mount.scad":      ["mount"],
  ```
- **`docs/bom.md`**: la tabla de tornillería pierde la fila "Placa → mordaza"
  (ya no hay placa) y las dos filas de apriete de gancho se funden en una
  ("Apriete del mount al borde", 1 tornillo en vez de 2). La tabla de piezas
  impresas pasa de 7 a 5: `mount`, `pod`, `knob`, `box`, `lid`.
- **Spec de 2026-09-04**: se le añade una nota apuntando a este documento en
  la sección "Diseño 3D", en vez de reescribir su contenido (ese spec sigue
  siendo válido para todo lo que no cambia: sensado, montaje general,
  firmware, Grafana).

## Piezas: antes → después

| Antes (7 piezas) | Después (5 piezas) |
|---|---|
| `clamp` | fusionada en `mount` |
| `hook` | fusionada en `mount` |
| `plate` | eliminada (bisagra de fricción no la necesita) |
| `pod` | `pod` (oreja de fricción en vez de disco Hirth) |
| `knob` | `knob` (sin cambios) |
| `box` | `box` (sin cambios) |
| `lid` | `lid` (sin cambios) |

## Validación

`python cad/build.py` sigue siendo la herramienta de verificación: exporta
las 5 piezas, corre los `echo` de geometría y tornillería, y falla con código
de salida distinto de cero si algún `assert` salta (huecos del PCB, ventana
óptica, tornillos del gancho fuera de sitio). Se añade una comprobación nueva
específica de este cambio: que la interfaz `mount`→`box` reproduzca los
agujeros de la espina dentro de una tolerancia de 0, no aproximada — un
`assert` que compare las constantes copiadas contra las originales de
`electronics_box.scad` para que un futuro cambio en uno de los dos archivos
no los desincronice en silencio.

## Riesgos abiertos

| Riesgo | Impacto | Mitigación |
|---|---|---|
| Fricción pura sin detentes puede aflojarse con vibración o uso | El ángulo se corre y la calibración deja de ser repetible | Arandela de presión si está disponible; recalibrar en Grafana tras cada desmonte; documentado en `docs/calibration.md` |
| La ventana óptica real del TOF200C (ranura ovalada 9.6×5 mm) es más ancha que lo que permite `window_d` con `pcb_w=11` | Posible vignetting si la óptica activa del chip no está centrada en la zona que sí cubre `window_d=7.5` | Medir con el módulo en mano antes de imprimir el `pod` definitivo: si el área óptica activa cae dentro de los 7.5 mm centrales, no hay problema real |

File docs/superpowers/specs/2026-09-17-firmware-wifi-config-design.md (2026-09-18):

# Firmware, WiFi provisioning y config web — Diseño

**Fecha:** 2026-09-17
**Estado:** aprobado, pasando a implementación directa (sin plan intermedio separado)
**Contexto:** extiende [2026-09-04-egg-basket-monitor-design.md](2026-09-04-egg-basket-monitor-design.md). El CAD ya está implementado; el firmware no existía hasta ahora.

## Cambio respecto al diseño original

El diseño del 2026-09-04 asumía credenciales de WiFi y Grafana en un
`include/secrets.h` compilado dentro del firmware (gitignored, con un
`.example` commiteado). Eso obliga a reflashear para cambiar de red WiFi o
rotar el token de Grafana.

Se reemplaza por **configuración en runtime vía portal cautivo**: el
dispositivo, si no tiene configuración guardada (o si se le pide
explícitamente), levanta su propio punto de acceso WiFi con un formulario web
donde se cargan tanto las credenciales de WiFi como los parámetros de Grafana
Cloud y el intervalo de sueño. Todo se guarda en NVS (flash) vía la librería
`Preferences` de Arduino-ESP32. `secrets.h` desaparece del diseño.

## Sensor: corrección de nombre

El sensor es el **VL53L1X** de STMicroelectronics (no "BL53LD", una
transcripción incorrecta). Ya estaba fijado por el diseño original con una
justificación detallada (ROI configurable para estrechar el cono del receptor
en el montaje diagonal). Se mantiene sin cambios: mismo pinout, misma
librería (`pololu/VL53L1X`), mismo modo `short`.

## Máquina de estados de arranque

Cada arranque (wake por timer, power-on, o reset manual) ejecuta esta
decisión antes de cualquier otra cosa:

```
setup()
  │
  ├─ Leer GPIO9 (BOOT) durante una ventana de 8-9 s desde el arranque
  │
  ├─ Sin NVS de WiFi guardada           → CONFIG_MODE (primer arranque)
  ├─ BOOT sostenido 3-8 s               → CALIBRATION_MODE (ya existía)
  ├─ BOOT sostenido > 8 s               → CONFIG_MODE (reconfigurar)
  └─ Ningún botón / NVS válida          → NORMAL_MODE (ciclo de medición)
```

La ventana de detección de 8-9 s hace que el usuario nunca tenga que adivinar
cuánto aguantar: se limpia con feedback de LED (ver abajo). El costo en
batería de esta ventana es despreciable porque solo se ejecuta lectura de
GPIO, sin radio ni sensor activos.

### Feedback por LED (GPIO8, RGB integrado del C3 SuperMini)

El original evitaba GPIO8 para I2C por ser pin de strapping, pero como salida
de estado post-arranque es su uso nativo en la placa y no interfiere con el
boot (el strapping solo importa durante el reset).

| Evento | Patrón |
|---|---|
| Botón detectado, aún en ventana de decisión | Parpadeo lento blanco/azul mientras se cuenta |
| Entra a `CALIBRATION_MODE` | Dos parpadeos verdes |
| Entra a `CONFIG_MODE` | Tres parpadeos azules, luego encendido fijo mientras el AP está activo |
| POST a Grafana exitoso | Un parpadeo verde corto antes de dormir |
| POST fallido (buffer a RTC) | Un parpadeo rojo corto antes de dormir |
| Batería < 3.3 V, corte | Tres parpadeos rojos antes del sueño indefinido |

## CONFIG_MODE: portal cautivo

Implementado con **WiFiManager** (tzapu/WiFiManager vía PlatformIO
`lib_deps`), no un servidor a medida: maneja AP, DNS captivo y el formulario
de selección de red, y admite parámetros custom (`WiFiManagerParameter`) para
todo lo que no es WiFi.

- **SSID del AP:** `EggBasket-Setup`
- **Password del AP:** `eggbasket2026` (constante en `src/config.h`,
  documentada en el tutorial, cambiable antes de flashear)
- **Timeout del portal:** 5 minutos sin actividad → `ESP.restart()` y vuelve
  al ciclo normal. Evita drenar la batería si el modo se activó sin querer.
- **Un solo formulario combinado**, con estos campos además de SSID/password
  de WiFi:

  | Campo | Tipo | Notas |
  |---|---|---|
  | Influx write URL | texto, requerido | URL completa, p.ej. `https://influx-prod-XX.grafana.net/api/v1/push/influx/write` |
  | Instance ID (usuario Basic Auth) | texto, requerido | |
  | API token (password Basic Auth) | password, requerido, maxlength 150 | Access Policy token de Grafana Cloud |
  | Device tag | texto, default `cocina` | Va en el line protocol como `device=<tag>` |
  | Intervalo de sueño (minutos) | numérico, default 60, rango 5-1440 | |

- Al guardar: todos los campos se escriben en `Preferences` (namespace
  `cfg`), y el dispositivo reinicia. El próximo arranque entra en
  `NORMAL_MODE` porque ya hay WiFi guardado y no hay botón presionado.
- Validación: `required` en HTML más chequeo en el callback de guardado
  (ningún campo obligatorio vacío); si falla, el portal no cierra y muestra
  el formulario de nuevo.

**Riesgo aceptado y documentado:** el password del AP es una constante en un
repo público. Es un riesgo bajo (ventana de minutos, en la propia casa) pero
se documenta explícitamente en el README para que quien clone el repo decida
si quiere cambiarlo.

## NORMAL_MODE: ciclo de medición (sin cambios de fondo respecto al original)

1. `XSHUT` alto, iniciar VL53L1X, aplicar ROI reducido, modo `short`.
2. 20 lecturas → mediana, desviación estándar, conteo de válidas.
3. `XSHUT` bajo (standby, ~5 µA).
4. Leer batería en GPIO3 vía el divisor 1M/1M. Si `< 3.3 V`: LED de corte,
   `esp_deep_sleep_start()` sin timer (sueño indefinido), fin.
5. Cargar config de `Preferences`. `WiFi.begin(ssid, pass)`, esperar conexión
   con timeout de 15 s.
6. Si conecta: armar línea(s) Influx (la actual + cualquiera pendiente en el
   buffer RTC), POST HTTPS con Basic Auth, `text/plain`.
   - Éxito (2xx): vaciar buffer RTC, LED verde.
   - Fallo (timeout, no-2xx, sin WiFi): guardar la muestra actual en el
     buffer RTC (anillo de 3, la más vieja se descarta si está lleno), LED
     rojo.
7. `WiFi.disconnect(true)`.
8. `esp_sleep_enable_timer_wakeup(sleep_minutes * 60 * 1e6)`,
   `esp_deep_sleep_start()`.

### Buffer de reintento en RTC

`RTC_DATA_ATTR` struct con 3 slots `{distance_mm, stddev_x10, valid_count,
battery_mv, minutes_ago, occupied}`. `minutes_ago` se incrementa en cada
ciclo fallido adicional y se usa para calcular el timestamp explícito en la
línea Influx reenviada (Influx line protocol acepta timestamp en el mismo
POST). Esto sobrevive deep sleep porque la RTC slow memory no se borra entre
ciclos (solo se borra con power-on-reset real, ej. batería quitada).

### Línea Influx

```
eggbasket,device=<tag> distance_mm=<n>,stddev=<f>,valid=<n>,status=<0|1>,battery_mv=<n>,rssi=<n>,boots=<n> [timestamp_ns]
```

`status=1` marca una muestra reenviada desde el buffer (para poder filtrarlas
o auditarlas en Grafana si hace falta). `boots` es un contador persistido en
RTC memory que sobrevive deep sleep (se resetea solo con power-on-reset).

## Estructura del firmware

```
firmware/
├── platformio.ini
├── include/
│   └── config.h            # constantes: pines, SSID/pass del AP, timeouts
├── src/
│   ├── main.cpp             # setup() con la máquina de estados de arranque
│   ├── boot_mode.h/.cpp      # detección de BOOT sostenido + LED feedback
│   ├── sensor.h/.cpp         # init VL53L1X, ROI, 20 lecturas, mediana/stddev
│   ├── settings.h/.cpp       # wrapper de Preferences (NVS): get/set config
│   ├── portal.h/.cpp         # WiFiManager + parámetros custom + callback de guardado
│   ├── telemetry.h/.cpp      # línea Influx, POST HTTPS, buffer RTC de reintento
│   └── power.h/.cpp          # lectura de batería, deep sleep, LED
```

Sin `secrets.h`: no hay ningún credential en el repo, todo vive en NVS del
dispositivo en runtime.

## Pinout (sin cambios respecto al original, se documenta con diagrama)

| Señal | Pin C3 SuperMini | Va a |
|---|---|---|
| SDA | GPIO4 | VL53L1X SDA |
| SCL | GPIO5 | VL53L1X SCL |
| XSHUT | GPIO6 | VL53L1X XSHUT |
| ADC batería | GPIO3 | Nodo medio divisor 1MΩ/1MΩ |
| Botón BOOT/config | GPIO9 | Botón BOOT de la placa (pull-up interno) |
| LED de estado | GPIO8 | RGB integrado de la placa |
| 3V3 / GND | — | VL53L1X VCC / GND, extremo superior del divisor a 3V3, inferior a GND |

Se agregan a `docs/wiring.md`: tabla (la de arriba), diagrama de conexión
tipo breadboard (SVG) y diagrama esquemático simplificado (SVG), ambos
locales en `docs/img/`.

## Documentación nueva

- `docs/wiring.md`: pinout + diagramas SVG + cadena de alimentación.
- `docs/setup-tutorial.md`: flasheo con PlatformIO, primer arranque, conexión
  al AP `EggBasket-Setup`, llenado del formulario, verificación en Grafana
  Cloud, tabla de patrones de LED, cómo volver a `CONFIG_MODE` o
  `CALIBRATION_MODE`.
- `docs/calibration.md`: uso del modo de calibración por serial (ya descrito
  en el spec original) para elegir el detente de la articulación Hirth.
- `README.md`: sección "Firmware" enlazando a los tres documentos de arriba.

## Fuera de alcance (sin cambios respecto al original)

- PCB a medida, conteo exacto de huevos, multi-canasta, Home Assistant.
- Cifrado de flash / NVS encriptada: el token de Grafana queda en NVS en
  texto plano. Riesgo aceptado para un dispositivo doméstico; se documenta.
- Verificación en hardware real: este documento y el código que sigue se
  desarrollan sin el dispositivo físico presente. La compilación con
  PlatformIO no se pudo verificar en esta máquina (CLI no instalado). Queda
  pendiente compilar y probar en hardware antes de dar el firmware por
  bueno.

## Criterios de éxito (agregados a los del spec original)

6. Desde cero (sin NVS), el dispositivo levanta `EggBasket-Setup`, acepta el
   formulario combinado, guarda config y arranca en `NORMAL_MODE` sin
   reflashear.
7. Mantener BOOT > 8 s en cualquier arranque reabre el portal sin perder la
   config anterior hasta que se guarde una nueva.
8. Una falla de POST no pierde la muestra: aparece en el siguiente envío
   exitoso con su timestamp original.

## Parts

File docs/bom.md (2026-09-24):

# Lista de materiales

Todo son módulos ya hechos que se conectan con cable Dupont. **No hay PCB
custom** y no hace falta soldar nada salvo dos resistencias y los dos contactos
de la celda (nunca sobre la celda).

## Ya lo tienes — coste 0

| Componente | Nota |
|---|---|
| ESP32-C3 SuperMini | Con sus limitaciones ya contempladas en el diseño: sin cargador de litio, sin divisor de batería, deep sleep de fábrica ~500 µA |
| Celda 18650 | El hueco de la caja acepta de 62 a 69 mm, así que da igual si es protegida o no |
| Resorte de bolígrafo | Contacto negativo. Es lo que absorbe la diferencia de largo entre celdas |
| Lámina de latón o clip metálico | Contacto positivo |
| Cable USB-C | Para cargar y para flashear |
| Filamento PETG | ~90 g entre las cinco piezas. PETG y no PLA: la cocina tiene calor y grasa |

## Hay que comprar — AliExpress, ~USD 8-12

| # | Componente | Búsqueda | USD |
|---|---|---|---|
| 1 | Módulo ToF TOF200C (VL53L0X) | `TOF200C VL53L0X` | 2-4 |
| 2 | TP4056 **con protección**, USB-C | `TP4056 USB-C protection DW01` | 0.60 |
| 3 | Resistencias 1 MΩ 1% (×2) — o cualquier par igual que ya tengas, ver nota abajo | `1M ohm 1% resistor` | 0.20 |
| 4 | Dupont hembra-hembra 20 cm (pack 40) | `dupont female female 20cm` | 1-2 |
| 5 | Termorretráctil surtido | `heat shrink tube assortment` | 1 |
| 6 | Tornillería M3 + M2 (ver abajo, seguramente ya la tienes) | `M3 hex socket screw assortment kit` | 0-3 |

### Los dos ítems que importan

**El sensor (ítem 1).** El módulo instalado es un TOF200C, con un **VL53L0X**
(el diseño original pedía un VL53L1X; el CAD ya está acotado para el
TOF200C). No confundir con un VL53L1X: contestan en la misma dirección I2C
pero necesitan librerías distintas, ver `docs/wiring.md`. El TOF200C trae
regulador propio: conviene medir su consumo en reposo con XSHUT bajo, porque
un regulador con corriente de reposo alta (un AMS1117 ronda los 5 mA, 50× el
resto del circuito dormido) acorta la batería de meses a semanas. Plan B: un
load switch con MOSFET-P (~USD 1) que le corte la alimentación entera durante
el sueño. Si el cono fijo de 25° del VL53L0X mide las paredes de la canasta,
la alternativa es el TOF400C (VL53L1X), con ROI.

**El TP4056 (ítem 2).** Tiene que ser la variante **con protección** (lleva un
DW01A y un FS8205A junto al chip principal). La versión sin protección es un
céntimo más barata y deja la celda sin corte por sobredescarga ni por
cortocircuito. No es negociable con una celda desnuda.

## Tornillería

**Todo es tornillería de métrica normal. No hay ni un autorroscante.** Donde el
tornillo no encuentra nada al otro lado, el CAD embute una tuerca hexagonal en
la pieza y es ella la que hace de rosca: un hexágono a medida impide que gire,
así que la pieza se comporta como si llevara un inserto. Aguanta apretar y
aflojar indefinidamente, que es más de lo que da una rosca hecha en PLA.

Las longitudes las calcula el propio modelo al compilar (`python cad/build.py`),
así que si tocas una cota del CAD, vuelve a mirar aquí. Con las cotas actuales:

| Dónde | Tornillo | Tuerca | Cant. |
|---|---|---|---|
| Pivote de la bisagra de fricción | M3×22, rosca completa (mínimo 22) | 1 cautiva en el mount + 1 en el pomo | 2 + 1 arandela suelta |
| Apriete del mount al borde | M3×16 (mínimo 12.2) | 1, cautiva en el saliente | 1 |
| Mount → caja (interfaz heredada del gancho original) | M3×14 | 2, embutidas en la espina de la caja | 2 |
| Tapa de la caja | M3×8 | 4, cautivas bajo la tapa | 4 |
| Módulo VL53L1X al pod | M2×8 (mínimo 7.7) | 2, sueltas por detrás del PCB | 2 |

**Total: 9 tornillos M3, 2 tornillos M2, 9 tuercas M3, 2 tuercas M2, 1 arandela M3.**

El tornillo del pivote necesita ser de **rosca completa** (no parcial): rosca
tanto en la tuerca cautiva del mount como en la del pomo, en los dos extremos.
La mayoría de los M3 cortos de un kit de tornillería ya vienen así.

`clamp`, `plate` y `hook` desaparecieron en el rediseño de 2026-09-18: se
fusionaron en una sola pieza (`mount`) con un solo punto de apriete, y la
bisagra Hirth se reemplazó por fricción pura (tornillo + arandela, sin
detentes). Ver `docs/superpowers/specs/2026-09-18-cad-rim-mount-redesign-design.md`.

Dos detalles de montaje:

- Las tuercas de las cuatro orejas de la tapa se caen si vuelcas la caja: se
  ponen justo antes de cerrar, y es la tapa la que las retiene.
- Las dos tuercas M2 del sensor aprietan contra un PCB desnudo. Con los dedos,
  no con llave: a llave se raja.

## Dónde van las dos resistencias

El ESP32-C3 SuperMini no trae divisor de batería, así que hace falta uno de
1 MΩ/1 MΩ para leer la tensión de la celda por GPIO3. **No lleva protoboard**:
son dos componentes, se sueldan en línea sobre un Dupont y se aíslan con
termorretráctil. Una miniprotoboard de 170 puntos mide 47×35 mm y no cabe en el
vano de la caja, que tiene 32 mm de ancho.

El divisor consume 2.1 µA permanentes con 1 MΩ, despreciable frente a los
~500 µA del deep sleep de la placa.

**No hace falta que sean 1 MΩ exactos.** Lo único que importa es que las dos
resistencias sean del mismo valor entre sí — el punto medio siempre queda a
la mitad del voltaje de la batería sin importar la magnitud. Si tenés a mano
un par de 100 kΩ (código de colores café-negro-amarillo), sirven igual: el
consumo sube a ~21 µA, todavía chico frente a los ~500 µA de la placa
(~0.5 mAh/día extra sobre un presupuesto total de ~16.6 mAh/día, un par de
días menos de autonomía sobre ~4 meses). El firmware no cambia:
`BATTERY_DIVIDER_RATIO` en `firmware/include/config.h` sigue siendo `2.0f`
porque depende de que R1 = R2, no de su valor.

## Lo que ya NO hace falta

Tres ítems que estaban en la primera versión de la lista y han caído al avanzar
el CAD:

- **Imanes de neodimio 6×3.** La caja iba a fijarse al mueble con imanes. Ahora
  cuelga del borde con su propio gancho impreso, igual que la cabeza del sensor.
- **Tornillos autorroscantes.** Los usaban la tapa de la caja, los dos tornillos
  de apriete y el módulo del sensor. Todos son ahora de métrica normal contra
  tuerca; ver la tabla de arriba.
- **Miniprotoboard de 170 puntos.** Ver arriba: no cabe y no hace falta.

## Piezas impresas

Cinco, ninguna necesita soportes. `python cad/build.py` las exporta todas a
`cad/out/`.

| Pieza | Orientación |
|---|---|
| `mount` | De canto |
| `pod` | Con la oreja de la bisagra hacia arriba |
| `knob` | Plana |
| `box` | Boca hacia arriba |
| `lid` | Plana |

⚠️ **Janus (Voron Trident)** tiene `[homing_override]` en Z que arranca con
`G0 Z10` y cruza la cama en diagonal. Retira cualquier pieza alta de la cama
antes de lanzar el print o un `G28` pelado estrella el cabezal.

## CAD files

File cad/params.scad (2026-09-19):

// ===========================================================================
//  egg-basket-monitor  ::  parametros globales
//  Toda cota que puedas necesitar cambiar vive AQUI. Ningun otro archivo
//  deberia tener numeros magicos.
// ===========================================================================

/* [Canasta] --------------------------------------------------------------
   Solo `rim_thickness` afecta a la geometria de la mordaza. Las otras tres
   medidas se usan unicamente para calcular el rango util de angulos y para
   la vista de contexto. Cambiar de canasta = cambiar rim_thickness.        */

basket_width   = 300;   // mm, lado largo de la boca
basket_depth   = 150;   // mm, lado corto de la boca
basket_height  = 500;   // mm, del borde al fondo
rim_thickness  = 10;    // mm, espesor de la pared donde muerde la mordaza

/* [Optica del VL53L1X] ---------------------------------------------------
   El emisor dispara SIEMPRE un cono de 27 grados y eso no es configurable.
   Solo el receptor admite ROI, hasta un minimo de 15 grados con 4x4 SPADs.
   Ese 15 es el numero que manda para el calculo de angulos.                */

emitter_cone = 27;      // grados, fijo por hardware
roi_fov      = 15;      // grados, ROI de 4x4 SPADs (el mas estrecho posible)
wall_margin  = 20;      // mm que el borde del ROI debe dejar libres contra
                        // cualquier pared en el fondo de la canasta

/* [Mordaza] ------------------------------------------------------------- */

clamp_width      = 26;    // mm a lo largo del borde
clamp_wall       = 3.2;   // mm de pared
clamp_grip_in    = 34;    // mm que baja por dentro (pata del brazo del sensor)
clamp_clearance  = 0.8;   // holgura sobre rim_thickness
clamp_screw_d    = 3.4;   // M3 pasante para el tornillo de apriete
grip_ribs        = true;  // nervios antideslizantes dentro de la mordaza

/* [Tornilleria] ----------------------------------------------------------
   Todos los tornillos del proyecto son de METRICA NORMAL, de los de toda la
   vida. Ni uno solo es autorroscante, a proposito: donde el tornillo no
   encuentra nada al otro lado, se embute una tuerca hexagonal en la pieza y
   es ella la que hace de rosca. Sale mas fiable que roscar en PLA —se puede
   apretar y aflojar mil veces— y no obliga a comprar tornilleria especial.

   Cotas DIN 934 nominales. Si tus tuercas son de otro sitio, midelas: la
   holgura de estos alojamientos es cero a proposito, para que no giren.     */

nut_af    = 6.2;   // entrecaras de la tuerca M3 (5.5 nominal + holgura)
nut_h     = 2.8;   // espesor de la tuerca M3
m2_nut_af = 4.2;   // entrecaras de la tuerca M2 (4.0 nominal + holgura)
m2_nut_h  = 1.6;   // espesor de la tuerca M2

/* [Pivote] -----------------------------------------------------------------
   pivot_drop: mm del borde de la canasta al eje de la bisagra de friccion.  */

pivot_drop = 28;

/* [Pomo de apriete] ----------------------------------------------------- */

knob_d     = 24;
knob_h     = 9;
knob_lobes = 6;

/* [Bisagra de friccion] ---------------------------------------------------
   Reemplaza a la articulacion Hirth: una oreja plana en el mount con una
   tuerca M3 cautiva, y otra oreja lisa en el pod, con una arandela entre
   las dos caras de contacto. El tornillo entra por el pomo, atraviesa el
   pod y rosca en la tuerca del mount. Sin detentes: el angulo se fija por
   friccion pura. Recalibrar en Grafana tras tocar el pivote.

   La tuerca va del lado de la mordaza/borde (-Y), en un alojamiento
   hexagonal abierto a esa cara: no queda tapada por ninguna otra pieza, la
   sujeta solo el hexagono (no puede girar) y la presion del tornillo una
   vez apretado.                                                            */

hinge_screw_d  = 3.4;   // mm, M3 pasante del pivote
hinge_ear_w    = 22;    // mm, ancho x alto de cada oreja (mount y pod)
hinge_ear_t    = 6.0;   // mm, espesor de cada oreja (>= nut_h + 3, la tuerca
                        // del mount se embute por su cara y debe quedar
                        // material detras, hacia el lado del pod)
hinge_arm_t    = 6.0;   // mm, espesor del brazo que conecta la pata del
                        // mount con la oreja (mismo grosor que la oreja)
                        // Entre las dos orejas va una arandela M3 suelta,
                        // sin modelar: es hardware de compra, no impreso.

/* [Angulo de apuntado] ---------------------------------------------------
   0 grados = mirando recto hacia abajo, pegado a la pared.
   Positivo = inclinado hacia el interior de la canasta.
   El maximo seguro lo calcula geometria.scad; no lo fijes a ojo.           */

angle_min     = 0;
angle_max     = 30;
angle_preview = 16;    // solo para la vista de ensamblaje (debe caer dentro
                       // del rango que calcula lib/geometry.scad)

/* [Modulo VL53L1X] -------------------------------------------------------
   MEDIR EL MODULO REAL CUANDO LLEGUE. Los breakout de AliExpress varian
   entre 20x11 y 25x13 mm y la separacion de agujeros cambia con cada lote. */

pcb_l            = 20.0;  // mm, ancho real del TOF200C
pcb_w            = 11.0;  // mm, alto del PCB
pcb_t            = 1.6;   // mm, espesor del PCB (sin medir, se mantiene)
pcb_hole_spacing = 14.4;  // mm entre centros de agujero, ficha del TOF200C
pcb_hole_d       = 2.3;   // mm, M2 PASANTE (agujero real Ø2, esto da holgura)
pcb_pocket_clear = 0.4;   // holgura del bolsillo
// Ventana optica. Tiene que dejar pasar el cono de 27 grados desde la
// apertura del sensor a traves del material que queda por delante del PCB
// (wall_t menos la profundidad del bolsillo, unos 4 mm):
//     2 * (2.7 + 4*tan(13.5)) = 7.3 mm
// Y no mas: el bolsillo mide pcb_w + 0.8 de alto, asi que cada milimetro de
// ventana se lo come al reborde donde apoya el PCB. Con Ø8 el apoyo bajaba a
// 1.9 mm y el assert de sensor_head.scad salta. Ø7.5 deja 2.15 mm.
window_d         = 7.5;   // mm
optics_offset    = 0;     // mm, del centro del PCB al eje optico (medir)
wire_channel_d   = 6.0;   // mm, canal para los 5 Dupont

/* [Alcance del brazo] ----------------------------------------------------
   Cuanto se mete el sensor hacia el interior de la canasta, medido desde
   la cara interna de la pared. Alejar el sensor de la pared es la unica
   defensa fisica real contra que el cono del emisor la ilumine.
   No se pone una capota: una capota recortada a 27 grados no bloquea nada
   que este dentro del cono, y la pared cercana esta dentro del cono.       */

pod_reach = 16;   // mm, de la cara interna de la pared al eje del pivote

// Del eje del pivote al centro del sensor: lo justo para que la pared del
// PCB libre la oreja de la bisagra de friccion. Vive aqui, y no dentro de
// sensor_head.scad, porque geometry.scad lo necesita para saber donde acaba
// mirando el sensor.
pod_arm = hinge_ear_w / 2 + pcb_w / 2 + 6;   // mm

/* [Caja de electronica] --------------------------------------------------
   Cuelga POR FUERA de la canasta, con su propio gancho al borde. Va fuera y
   no dentro por dos razones: la celda de litio no queda suspendida sobre la
   comida, y su peso contrarresta el del pod, que tira hacia dentro.

   Tambien se sostiene de pie sobre una mesa sin el gancho: la cara de abajo
   es plana a proposito.

   MEDIR LOS MODULOS REALES CUANDO LLEGUEN. Los clones de AliExpress varian.  */

cell_d = 18.6;   // mm, diametro del 18650 (nominal 18.4-18.6)
cell_l = 68;     // mm de hueco: 65 de celda mas el muelle, que come holgura

// Contactos. Nada se suelda a la celda: el cable se suelda al muelle y a la
// lamina ANTES de montarlos, que es igual de fiable y mucho menos peligroso.
spring_d = 7.5;  // nicho del muelle de boligrafo, polo negativo
spring_h = 3.5;  // profundidad del nicho (el muelle va comprimido, no libre)
strip_w  = 10;   // rebaje de la lamina de laton, polo positivo
strip_t  = 0.8;

tp_l  = 26;   tp_w  = 17;   tp_t = 5;    // TP4056 con proteccion
mcu_l = 22.5; mcu_w = 18;   mcu_t = 6;   // ESP32-C3 SuperMini
board_recess = 1.5;                      // alto del reborde que sitia el modulo
// El hueco es para el CONECTOR MACHO con su funda, no para el receptaculo.
usb_w = 12.5; usb_h = 7.5;

box_wall    = 2.4;
box_lid_t   = 2.4;
box_screw_d = 3.4;   // M3 de la tapa
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

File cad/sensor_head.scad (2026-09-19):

// ===========================================================================
//  egg-basket-monitor  ::  cabeza del sensor
//
//  Se cuelga del borde de la canasta y apunta el VL53L1X hacia el fondo con
//  un angulo regulable por friccion (sin detentes). Solo depende de
//  `rim_thickness`: sirve para cualquier canasta cambiando ese numero.
//
//  El punto de apriete al borde y la oreja de la bisagra viven ahora en
//  `rim_mount.scad` (pieza `mount`, fusiona lo que antes eran `clamp` +
//  `plate` + el `hook` de la caja de electronica). Este archivo se queda con
//  las dos piezas que dependen del sensor en si:
//    pod   -> plano, oreja de friccion hacia -Y
//    knob  -> plano
//
//  TORNILLERIA: las longitudes las calcula y las imprime el propio modelo al
//  compilar. Ver el bloque ECHO.
//
//  ORDEN DE MONTAJE:
//    1. Tuerca M3 a presion en la oreja del mount (rim_mount.scad), del
//       lado de la mordaza/borde (queda abierta a esa cara, no cautiva por
//       otra pieza: la sujeta el hexagono y despues el propio tornillo).
//    2. Tuerca M3 a presion en el pomo.
//    3. Pod contra la oreja del mount, con la arandela entre las dos
//       caras. Tornillo de rosca completa desde el pomo, atraviesa el pod,
//       rosca en la tuerca del mount. Apretar el pomo a mano hasta que la
//       friccion sujete el angulo.
//
//  Uso:  openscad -D 'part="pod"' -o pod.stl sensor_head.scad
//        part = "pod" | "knob" | "assembly"
// ===========================================================================

include <lib/geometry.scad>    // arrastra params.scad y valida el apuntado
include <lib/rim_hook.scad>    // perfil en U, compartido con rim_mount.scad

part = "assembly";

// --- Cotas derivadas -------------------------------------------------------
px = rim_thickness + pod_reach;   // X del eje del pivote (global)
pz = -pivot_drop;                 // Z del eje del pivote (global)

// La oreja del pod queda pegada a la oreja del mount (ver rim_mount.scad):
// el mount ocupa hasta su cara +Y (clamp_width/2), la oreja del pod arranca
// justo ahi y crece hinge_ear_t hacia afuera.
y_ear_mount = clamp_width / 2;
y_pod       = y_ear_mount + hinge_ear_t;

wall_t = 6;    // espesor de la pared que sujeta el PCB
eps    = 0.01;

rib_t = 3.0;   // nervios brazo-pared del pod
rib_h = 12;
rib_l = 12;

// De la cara delantera de la pared a la cara lejana de la tuerca, pasando
// por el fondo del bolsillo y el PCB.
sensor_len = wall_t - pcb_pocket_clear + m2_nut_h + 0.5;

echo(str("--- Tornilleria pod ------------------------------------------"));
echo(str("  Sensor  M2 x ", round(sensor_len * 10) / 10,
         " mm  x2 + 2 tuercas (sueltas, por detras del PCB)"));
echo(str("=========================================================="));

// --- Que modulos VL53L1X caben ---------------------------------------------
pcb_support = (pcb_w + 2 * pcb_pocket_clear - window_d) / 2;
echo(str("--- Modulo VL53L1X ---------------------------------------"));
echo(str("  Con ", pcb_l, " x ", pcb_w, " mm el PCB apoya sobre ",
         round(pcb_support * 100) / 100, " mm de reborde"));
echo(str("  Ancho minimo del PCB: ", window_d + 4, " mm (ventana de ",
         window_d, " + 2 mm de apoyo por lado)"));
echo(str("  Separacion minima de agujeros: ",
         window_d + pcb_hole_d + 1, " mm (si no, el agujero cae en la ventana)"));
echo(str("=========================================================="));

assert(pcb_support >= 2,
       str("El PCB solo apoyaria sobre ", pcb_support, " mm. O el modulo es ",
           "mas ancho (pcb_w >= ", window_d + 4, ") o la ventana mas pequena."));
assert(pcb_hole_spacing / 2 > window_d / 2 + pcb_hole_d / 2 + 0.5,
       "Los agujeros de montaje del modulo caen dentro de la ventana optica.");
assert(pcb_hole_spacing < pcb_l - 2,
       "Los agujeros de montaje se salen del PCB. Revisa la medida.");

// ===========================================================================
//  POD DEL SENSOR   (frame local: origen en el eje del pivote, oreja en
//                    z ∈ [0, hinge_ear_t], direccion de apuntado = -Y)
// ===========================================================================

module pod() {
    pocket_l = pcb_l + 2 * pcb_pocket_clear;
    pocket_w = pcb_w + 2 * pcb_pocket_clear;
    body_h   = pocket_w + 2 * clamp_wall;

    // mirror([0,0,1]): la oreja y el brazo quedan en Z local <= 0 en vez de
    // >= 0. Sin esto, la unica rotacion que separa la oreja del pod de la
    // del mount (evitando que ocupen el mismo tramo de Y) es rotate(-90) en
    // X, pero esa MISMA rotacion invierte la direccion de apuntado del
    // sensor (apunta hacia el borde en vez de hacia el fondo). Con el
    // mirror, rotate(+90) en X -que es la que apunta bien- tambien separa
    // las orejas correctamente. Ver assembly() mas abajo.
    mirror([0, 0, 1])
    difference() {
        union() {
            // Oreja de friccion: reemplaza al disco Hirth. Un disco liso
            // de espesor hinge_ear_t con el agujero del pivote centrado.
            cylinder(d = hinge_ear_w, h = hinge_ear_t);

            // brazo, en el mismo plano que la oreja
            linear_extrude(hinge_ear_t, convexity = 4)
                hull() {
                    circle(d = hinge_ear_w * 0.75);
                    translate([0, -pod_arm + wall_t / 2])
                        square([pocket_l + 2 * clamp_wall, wall_t],
                               center = true);
                }

            // pared que sostiene el PCB, perpendicular al apuntado
            translate([0, -pod_arm + wall_t / 2, 0])
                linear_extrude(body_h)
                    square([pocket_l + 2 * clamp_wall, wall_t], center = true);

            // Dos nervios de refuerzo. Sin ellos, la oreja sujeta en
            // voladizo una pared de body_h de alto y la union en T se
            // parte al primer golpe.
            for (s = [-1, 1])
                translate([s * (pocket_l + clamp_wall) / 2,
                           -pod_arm + wall_t, 0])
                    rotate([0, 90, 0])
                        linear_extrude(rib_t, center = true)
                            polygon([[0, 0], [-rib_h, 0], [0, rib_l]]);
        }

        // Agujero del pivote.
        translate([0, 0, -eps])
            cylinder(d = hinge_screw_d, h = hinge_ear_t + 2 * eps);

        // Bolsillo del PCB, abierto por la cara trasera (+Y local).
        translate([-pocket_l / 2, -pod_arm + wall_t - (pcb_t + pcb_pocket_clear),
                   clamp_wall])
            cube([pocket_l, pcb_t + pcb_pocket_clear + eps, pocket_w]);

        // Ventana optica: atraviesa la pared en la direccion de apuntado.
        translate([optics_offset, -pod_arm + wall_t + 1, body_h / 2])
            rotate([90, 0, 0]) cylinder(d = window_d, h = wall_t + 2);

        // Pasantes M2 para el modulo. Pasantes y no pilotos: el tornillo
        // entra por delante, atraviesa la pared y el PCB, y aprieta contra
        // una tuerca M2 suelta por detras.
        for (s = [-1, 1])
            translate([s * pcb_hole_spacing / 2, -pod_arm + wall_t + 1,
                       body_h / 2])
                rotate([90, 0, 0]) cylinder(d = pcb_hole_d, h = wall_t + 2);

        // Salida de los Dupont por arriba.
        translate([0, -pod_arm + wall_t / 2, body_h - 1])
            cube([wire_channel_d, wall_t + 2, 6], center = true);
    }
}

// ===========================================================================
//  POMO DE APRIETE
// ===========================================================================

module knob() {
    difference() {
        union() {
            cylinder(d = knob_d * 0.72, h = knob_h);
            for (i = [0 : knob_lobes - 1]) rotate([0, 0, i * 360 / knob_lobes])
                translate([knob_d * 0.36, 0, 0]) cylinder(d = knob_d * 0.30, h = knob_h);
        }
        translate([0, 0, -eps]) cylinder(d = hinge_screw_d, h = knob_h + 1);
        translate([0, 0, -eps]) cylinder(d = nut_af / cos(30), h = nut_h + eps, $fn = 6);
    }
}

// ===========================================================================
//  ENSAMBLAJE  (solo para mirar; no se exporta)
// ===========================================================================

module basket_context() {
    color("Tan", 0.25) {
        translate([0, -60, -basket_height]) cube([rim_thickness, 120, basket_height]);
        translate([0, -60, -basket_height]) cube([basket_width, 120, 2]);
    }
}

module assembly() {
    basket_context();
    // rotate(+90) en X: es la que apunta el sensor hacia el fondo de la
    // canasta (-Z). El mirror() dentro de pod() es lo que evita que su
    // oreja choque con la del mount con esta misma rotacion.
    color("Crimson") translate([px, y_pod, pz])
        rotate([90, 0, 0]) rotate([0, 0, angle_preview]) pod();
    color("DimGray") translate([px, y_pod + hinge_ear_t + 1, pz])
        rotate([-90, 0, 0]) knob();
}
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

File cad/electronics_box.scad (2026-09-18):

// ===========================================================================
//  egg-basket-monitor  ::  caja de electronica
//
//  Celda 18650 + TP4056 + ESP32-C3 SuperMini. Cuelga POR FUERA de la canasta
//  con el mismo gancho al borde que la cabeza del sensor. Va fuera y no
//  dentro por dos razones: la celda de litio no queda suspendida sobre la
//  comida, y su peso contrarresta al del pod, que tira hacia dentro.
//
//  La cara de abajo es plana a proposito: sin el gancho, la caja se sostiene
//  de pie sobre la mesa.
//
//  TRES PIEZAS, ninguna necesita soportes:
//    box  -> con la boca hacia arriba
//    lid  -> plana
//    hook -> de canto (prisma puro, igual que la mordaza del sensor)
//
//  DISPOSICION: la celda va de pie contra una pared y los dos modulos al
//  lado, tumbados contra el fondo. Asi la caja queda de 24 mm de fondo en vez
//  de 32: pegada a la pared de la canasta hace menos palanca. Los 13 mm que
//  quedan libres por delante de los modulos no se desperdician, son para el
//  cableado Dupont, que abulta mas que los propios modulos.
//
//  Uso:  openscad -D 'part="box"' -o box.stl electronics_box.scad
//        part = "box" | "lid" | "hook" | "assembly"
// ===========================================================================

include <lib/rim_hook.scad>    // arrastra params.scad

part = "assembly";

// --- Cotas derivadas -------------------------------------------------------
// Marco: X a lo largo del borde, Y hacia arriba, Z hacia fuera de la canasta.
// Z=0 es la cara trasera, la que se apoya en la pared.

box_floor = 6;      // suelo grueso: dentro va el nicho del muelle
box_ceil  = 5;      // techo grueso: dentro va la lamina de laton
divider_t = 2.0;

cell_bay_w  = cell_d + 1;
// +6 y no +3: los clones de AliExpress varian de tamano y este margen es lo
// que permite meter un modulo 2-3 mm mayor sin volver a imprimir la caja.
board_bay_w = max(tp_l, mcu_l) + 6;

in_w = cell_bay_w + divider_t + board_bay_w;
in_h = cell_l + 2;                       // cell_l ya lleva holgura dentro
in_d = cell_d + 1;

out_w = in_w + 2 * box_wall;
out_h = box_floor + in_h + box_ceil;
out_d = box_wall + in_d;                 // sin la tapa

x0 = box_wall;            // cara interior de la pared -X
y0 = box_floor;           // cara superior del suelo
z0 = box_wall;            // cara interior del fondo
lid_z = z0 + in_d;

cx  = x0 + cell_bay_w / 2;      // eje de la celda
cz  = z0 + in_d / 2;
bx0 = x0 + cell_bay_w + divider_t;   // inicio del vano de modulos

// Tapa: cuatro orejas EXTERIORES, una por esquina, todas iguales.
//
// Antes eran dos bosses dentro y dos orejas fuera, y los tornillos roscaban
// directos en el plastico. Al pasar a tuerca cautiva los bosses dejaron de
// valer: en Ø7.5 no cabe una M3, que mide 7.16 de esquina a esquina y dejaria
// 0.17 mm de pared. Agrandarlos a Ø11 tampoco: el unico hueco libre del vano
// mide 2.75 mm. Asi que las cuatro se van fuera, donde hay sitio de sobra.
//
// Sale ganando el vano, que queda entero para los modulos y su cableado, y el
// unico precio es 19 mm mas de ancho en una pieza que cuelga por fuera.
ear_d  = 11;                             // Ø de la oreja (M3 + 1.9 de pared)
ear_cx = [-4, out_w + 4];                // solapan 1.5 mm contra la pared
lid_y  = [5.5, out_h - 5.5];

// La tuerca va embutida en la CARA DE ARRIBA de la oreja, justo debajo de la
// tapa, y es la tapa la que la mantiene en su sitio. Con la tuerca en la cara
// de abajo harian falta tornillos de 25 mm que ademas asomarian por detras.
ear_nut_z = out_d - nut_h - 0.3;

// Los dos modulos van pegados a la pared +X, no centrados: los dos sacan el
// USB-C por ahi y asi el conector queda enfrente de su agujero.
board_gap = 1.5;          // del canto del modulo a la cara interior de la pared
board_sep = 2;            // entre modulos, y del modulo a lo que tenga encima

// Apilados de abajo arriba desde el suelo. Derivados y no a mano para que al
// corregir las cotas de un modulo real todo lo demas se recoloque solo.
tp_y  = y0 + 6;
mcu_y = tp_y + tp_w + board_sep;

// Espina para colgar del mount: engorda la zona alta del tabique para poder
// embutir ahi dos tuercas M3. El mount unificado (rim_mount.scad) reproduce
// estos mismos agujeros desde su lado usando el bloque "Interfaz congelada"
// de params.scad (box_hook_*), asi que estos numeros de aqui NO se tocan.
hook_cx  = 30;
spine_y0 = y0 + in_h - 18;
spine_y1 = y0 + in_h;
spine_z  = 8;
hook_hole_y = [out_h - 10, out_h - 18];

be = 0.01;

// ===========================================================================
//  CAJA
// ===========================================================================

// Marco en relieve que posiciona un modulo. Se hace en relieve y no rebajado
// para no adelgazar el fondo, que solo tiene box_wall de espesor.
module board_frame(l, w, y) {
    fw = 1.5;             // ancho del marco
    fh = board_recess;    // alto
    x  = out_w - box_wall - board_gap - l - fit;   // alineado a la derecha
    difference() {
        translate([x - fw, y - fw, z0])
            cube([l + fit + 2 * fw, w + fit + 2 * fw, fh]);
        translate([x, y, z0 - 1])
            cube([l + fit, w + fit, fh + 2]);
    }
}

module box() {
    difference() {
        union() {
            // Cuerpo hueco, abierto por +Z.
            difference() {
                cube([out_w, out_h, out_d]);
                translate([x0, y0, z0]) cube([in_w, in_h, in_d + 1]);
            }

            // Tabique que impide que la celda se pase al vano de modulos.
            // Solo 10 mm de fondo: por delante pasan los cables.
            translate([x0 + cell_bay_w, y0, z0]) cube([divider_t, in_h, 10]);

            // Espina con las tuercas del gancho.
            translate([hook_cx - 7, spine_y0, z0]) cube([14, spine_y1 - spine_y0, spine_z]);

            // Orejas de la tapa, macizas de arriba abajo.
            for (x = ear_cx, y = lid_y)
                translate([x, y, 0]) cylinder(d = ear_d, h = out_d);

            board_frame(tp_l,  tp_w,  tp_y);
            board_frame(mcu_l, mcu_w, mcu_y);
        }

        // --- Tapa: tuerca cautiva por arriba y paso para la punta -----------
        for (x = ear_cx, y = lid_y) {
            translate([x, y, ear_nut_z])
                cylinder(d = nut_af / cos(30), h = nut_h + 0.3 + be, $fn = 6);
            translate([x, y, ear_nut_z - 7])
                cylinder(d = box_screw_d, h = 7 + be);
        }
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

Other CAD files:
cad/rim_mount.scad

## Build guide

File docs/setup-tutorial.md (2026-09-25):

# Tutorial: flasheo y primera configuración

## 1. Requisitos

- [PlatformIO](https://platformio.org/) (extensión de VS Code, o `pip install
  platformio` para el CLI).
- Cable USB-C.
- Cableado armado según `docs/wiring.md`.
- Una cuenta de Grafana Cloud con:
  - La URL de push Influx (Prometheus remote-write con la ruta cambiada a
    `/api/v1/push/influx/write`; en algunas regiones también cambia el host
    de `prometheus` a `influx`).
  - Un **Instance ID** (aparece en la página de detalles del datasource).
  - Un **Access Policy token** con permiso de escritura (`metrics:write`).

Grafana Cloud, dashboard y alertas de Telegram se configuran aparte — ver
`grafana/` cuando esos artefactos estén listos. Este tutorial cubre solo el
firmware.

## 2. Flashear

```bash
cd firmware
pio run -t upload
pio device monitor  # opcional, para ver los logs
```

`platformio.ini` ya lista las librerías necesarias (`WiFiManager`,
`pololu/VL53L0X`, `Adafruit NeoPixel`); PlatformIO las descarga solo en el
primer build.

No hay ningún `secrets.h` que editar: toda la configuración se carga después,
por WiFi.

## 3. Primer arranque: portal de configuración

Como el dispositivo recién flasheado no tiene ninguna red WiFi guardada,
entra automáticamente al **portal de configuración** sin necesidad de tocar
ningún botón.

1. El LED da tres parpadeos azules y queda fijo en azul: el portal está
   activo.
2. Desde tu celular o laptop, conectate a la red WiFi **`EggBasket-Setup`**
   con la contraseña **`eggbasket2026`** (cambiala en
   `firmware/include/config.h` antes de flashear si te preocupa que quede en
   un repo público).
3. Se debería abrir automáticamente una página de configuración (portal
   cautivo). Si no abre sola, andá a `http://192.168.4.1` en el navegador.
4. Elegí tu red WiFi de la lista y completá:
   - **Password** de esa red.
   - **Influx write URL**: la URL completa de Grafana Cloud.
   - **Instance ID**.
   - **API token**.
   - **Nombre del dispositivo** (por defecto `cocina`; usalo si en algún
     momento tenés más de una canasta).
   - **Intervalo de sueño (minutos)**: 60 por defecto, entre 5 y 1440.
5. Guardá. El dispositivo reinicia solo y arranca su ciclo normal: mide,
   se conecta a tu red, y hace un POST a Grafana Cloud.

Si no completás el formulario en 5 minutos, el dispositivo reinicia y vuelve
a intentar (si no hay config guardada, vuelve a levantar el portal).

## 4. Verificar que está funcionando

**Por serial (lo más rápido para probar).** Con el cable USB puesto, abrí el
monitor:

```bash
cd firmware
pio device monitor
```

Ojo: con el monitor abierto el dispositivo entra solo a **modo calibración**
(ver `docs/calibration.md`). Para ver el ciclo normal por serial, poner
`AUTO_CALIBRATION_ON_SERIAL` a `0` en `firmware/include/config.h` y volver a
flashear. Cada ciclo normal imprime algo así:

```
=== Ciclo normal ===
Sensor: distancia=412 mm  stddev=1.8  validas=19/20
Bateria: 4.05 V
Conectando a WiFi 'MiCasa'...
WiFi conectado: IP=192.168.1.47  RSSI=-52dBm
Influx POST -> HTTP 204
POST a Grafana Cloud: OK
Durmiendo 60 minutos...
```

Un `HTTP 204` (o cualquier 2xx) confirma que Grafana Cloud aceptó el dato. Si
falla, imprime el código HTTP y el cuerpo de la respuesta con el motivo (por
ejemplo `401` = token o Instance ID mal cargados en el portal, `404` = URL de
push incorrecta).

**En Grafana Cloud.** Explore, elegí el datasource Prometheus de tu stack y
corré:

```
eggbasket_distance_mm
```

Debería aparecer una serie con el label `device="cocina"` (o el nombre que
hayas puesto) actualizándose cada vez que pasa el intervalo configurado.

## 5. Forzar un envío sin esperar el intervalo

No hace falta ningún botón especial: **un RESET simple** (o desconectar y
reconectar la alimentación) alcanza, siempre que no mantengas BOOT
presionado al mismo tiempo. El ciclo normal se dispara en cada arranque, sea
por el temporizador de deep sleep o por un reset manual.

Para iterar más rápido mientras probás, también podés bajar el **intervalo
de sueño** a 5 minutos (el mínimo) desde el portal de configuración (sección
3, paso 4) en vez de resetear a mano cada vez.

## 6. Volver a entrar a un modo especial más adelante

Con la placa ya configurada, para forzar un modo especial hay que sostener
el botón **BOOT** justo cuando el dispositivo arranca (ver
`docs/wiring.md` para dónde está ese botón):

1. Mantené BOOT presionado.
2. Sin soltarlo, presioná y soltá **RESET** (o desconectá y reconectá la
   alimentación).
3. Seguí sosteniendo BOOT: el LED parpadea lento mientras cuenta.
   - Soltalo entre los 3 y 8 segundos → **modo calibración** (dos parpadeos
     verdes, después 60 s imprimiendo distancia cruda por serial a 2 Hz).
   - Seguí sosteniendo más de 8 segundos → **modo configuración** (tres
     parpadeos azules, vuelve a levantar `EggBasket-Setup`; tus credenciales
     WiFi anteriores no se borran hasta que guardes un formulario nuevo).

## 7. Tabla de patrones de LED

| Patrón | Significado |
|---|---|
| Parpadeo lento blanco/azul | Botón BOOT detectado, contando cuánto se sostiene |
| Dos parpadeos verdes | Entró a modo calibración |
| Tres parpadeos azules, luego fijo azul | Entró a modo configuración, portal activo |
| Un parpadeo verde corto | POST a Grafana exitoso, yéndose a dormir |
| Un parpadeo rojo corto | POST falló, muestra guardada para reintentar, yéndose a dormir |
| Tres parpadeos rojos | Batería bajo 3.3 V, entrando a sueño indefinido |

Si tu placa "C3 SuperMini" trae un LED simple de un solo color en vez de un
RGB direccionable, los mismos eventos se traducen a parpadeos simples (ver
`firmware/include/config.h`, `STATUS_LED_IS_NEOPIXEL`).

## 8. Qué hacer si algo no anda

- **El portal no abre / no aparece la red `EggBasket-Setup`.** Revisá el
  monitor serial (`pio device monitor`) para ver si el arranque detectó el
  modo correcto. Confirmá el cableado del botón BOOT (es el que ya trae la
  placa; no hay que cablear nada extra).
- **Conecta a WiFi pero nunca llegan datos a Grafana.** Con el monitor serial
  abierto, forzá un reset y mirá el log del ciclo normal (sección 4): el
  código HTTP que imprime `Influx POST -> HTTP ...` dice exactamente qué
  rechazó Grafana Cloud (401/403 = credenciales, 404 = URL, timeout = sin
  internet real aunque el WiFi haya conectado).
- **El sensor no inicializa** (mensaje de error en modo calibración, o
  "Sensor: fallo de lectura" en el log del ciclo normal): revisar
  `docs/wiring.md`, sección "Módulo del sensor", y confirmar que el chip es
  un VL53L0X (TOF200C); con un VL53L1X hay que volver a su librería.

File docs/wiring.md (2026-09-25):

# Cableado y pinout

Componentes: **ESP32-C3 SuperMini**, sensor ToF **VL53L0X** (módulo
**TOF200C**; ver "Módulo del sensor" más abajo), cargador **TP4056 con protección**, celda **18650**, divisor
resistivo de dos resistencias iguales (1 MΩ/1 MΩ nominal, pero sirve
cualquier par igual — ver la sección "Cadena de alimentación" más abajo).
Nada se suelda a la celda; ver `docs/bom.md` para el resto de materiales y
`cad/` para las piezas que sostienen todo esto físicamente.

## Diagramas

Esquema de conexionado

Cadena de alimentación

El esquema dibuja el SuperMini con sus 16 pines en la posición real (vista
desde arriba, USB-C arriba): los usados en dorado, los libres en gris. El
orden físico de los pines del TOF200C cambia según el fabricante, así que
guiate por el nombre serigrafiado. Ambos son SVG locales (sin dependencias
externas); se pueden abrir directamente en el navegador o en cualquier
editor de imágenes vectoriales para imprimir o anotar.

## ¿El número de pin es el que trae grabado la placa o un nombre de código?

**Es el mismo número.** En el ESP32-C3 SuperMini, el número serigrafiado
junto a cada pin *es* el número de GPIO: el pin marcado `4` en la placa es
`GPIO4`, sin ninguna traducción intermedia (a diferencia de placas estilo
NodeMCU/ESP8266, donde el pin marcado `D4` en realidad es `GPIO2`). Por eso
en el firmware (`firmware/include/config.h`) cada pin está definido dos
veces: una constante con el número tal como aparece en la placa
(`GPIO4_SDA`, `GPIO9_BOOT`, etc.) y un alias con el nombre funcional que usa
el resto del código (`PIN_I2C_SDA`, `PIN_BOOT_BUTTON`, etc.):

```cpp
constexpr int GPIO4_SDA = 4;          // marcado "4" en la placa
constexpr int PIN_I2C_SDA = GPIO4_SDA; // nombre que usa el resto del firmware
```

## Tabla de pines (ESP32-C3 SuperMini)

| Señal | GPIO (= número en la placa) | Va a | Por qué este pin |
|---|---|---|---|
| SDA (bus I2C) | GPIO4 | TOF200C SDA | Se evita el I2C por defecto del C3: GPIO8 es el LED RGB integrado y GPIO9 es el botón BOOT |
| SCL (bus I2C) | GPIO5 | TOF200C SCL | Ídem |
| XSHUT | GPIO6 | TOF200C SHUT | Bajo = apagado; el firmware lo lleva a GND entre lecturas y lo suelta (pull-up del módulo) para medir |
| ADC batería | GPIO3 | Nodo medio del divisor (dos resistencias iguales) | Único ADC libre tras reservar 4/5/6 |
| Botón BOOT / config | GPIO9 | Botón BOOT de la placa | Reutilizado: sostenerlo al arrancar decide el modo (ver `docs/setup-tutorial.md`) |
| LED de estado | GPIO8 | LED RGB integrado de la placa | Uso nativo del pin; solo importa como strapping *durante* el reset, no después |
| 3V3 / GND | — | TOF200C VIN / GND | Rieles de alimentación de la placa, sin número de GPIO |

**El bus I2C (SDA + SCL) es lo que conecta el sensor con el ESP32**, y es
bidireccional: SDA lleva datos en ambos sentidos, SCL es el reloj que genera
siempre el ESP32-C3 como maestro del bus. En el esquema, SDA va en azul y
SCL en amarillo, y XSHUT en verde para que no se confunda con el bus (XSHUT
sí es unidireccional, ESP32 → sensor).

## Cadena de alimentación

```
18650 (B+/B-) → TP4056 con protección (OUT+/OUT-)
             → pin 5V del ESP32-C3 SuperMini → LDO onboard → riel 3V3
                                              → divisor (R1=R2) → GPIO3
```

**El divisor no tiene que ser 1 MΩ/1 MΩ exactos.** Lo único que importa es
que las dos resistencias sean iguales entre sí: el punto medio siempre cae a
la mitad del voltaje de la batería sin importar la magnitud
(`V_medio = V_bateria × R2/(R1+R2)`, que da `V_bateria/2` cuando `R1=R2`).
Con un par de 100 kΩ (código de colores café-negro-amarillo) el divisor
consume ~21 µA en vez de ~2.1 µA — sigue siendo despreciable frente a los
~500 µA del deep sleep de la placa (ver `docs/bom.md`). El firmware no
cambia: `BATTERY_DIVIDER_RATIO` en `firmware/include/config.h` es `2.0f`
porque depende de que R1=R2, no de su valor absoluto.

**Riesgo abierto, a verificar con hardware en mano:** alimentar el pin 5V
directo con 3.7-4.2 V (el rango de una celda de litio) solo funciona bien si
la placa lleva un LDO de baja caída (p. ej. ME6211 o SGM2212, ~200 mV de
dropout). Si en cambio lleva un AMS1117 (1.1 V de dropout), el sistema se
apaga por debajo de ~4.4 V — es decir, con la celda todavía casi llena.

Cómo verificarlo: alimentar la placa desde una fuente de laboratorio variable
por el pin 5V, bajar la tensión lentamente desde 4.2 V y anotar en qué
voltaje el ESP32 hace brownout. Si el corte ocurre por encima de ~4.0 V, es
un AMS1117 y hay que cambiar de estrategia: alimentar el riel **3V3
directamente** desde un módulo HT7333 (quiescent ~4 µA) y no conectar USB y
batería al mismo tiempo mientras se usa esa ruta.

## Módulo del sensor: TOF200C (VL53L0X)

El módulo instalado es un **TOF200C**, que lleva un **VL53L0X**, no el
VL53L1X del diseño original. Los dos contestan en la dirección I2C `0x29` y
se parecen mucho, pero sus registros son incompatibles (8 bits en el
VL53L0X, 16 bits en el VL53L1X): con la librería del VL53L1X el escaneo I2C
encuentra el sensor pero `init()` falla siempre. El firmware usa la librería
`pololu/VL53L0X`. Para distinguirlos: registro `0xC0` = `0xEE` en el
VL53L0X; registro de 16 bits `0x010F` = `0xEACC` en el VL53L1X.

- **VIN a 3V3, no a 5V.** El TOF200C trae regulador y acepta 5V, pero sus
  pull-ups de SDA/SCL van a VIN y pondrían 5V en los GPIO del ESP32-C3.
- **Sin ROI.** El VL53L0X tiene el cono de 25° fijo; el VL53L1X permite
  estrecharlo. Si el cono toca las paredes de la canasta y las lecturas
  salen cortas, la salida es un módulo VL53L1X (se vende como **TOF400C**),
  que se conecta igual pero necesita volver a la librería `pololu/VL53L1X`.
- **Film protector.** Si mide siempre unos 20 mm, queda film en la ventana.

### Si se cambia a un módulo VL53L1X: qué versión pedir

Explícitamente la versión **pequeña de 3.3 V**. Si el módulo trae un
regulador AMS1117 igual que el punto anterior, su corriente de reposo
(~5 mA) es 50 veces el resto del circuito combinado en deep sleep, y la
batería dura semanas en vez de meses. Plan B si llega el módulo equivocado:
un load switch con MOSFET-P (~USD 1) que le corte la alimentación completa
durante el sueño, comandado desde el mismo pin que hoy maneja XSHUT.

## Botón BOOT: un solo botón, tres funciones

GPIO9 ya es el botón BOOT físico de la placa. El firmware lo reutiliza según
cuánto tiempo se sostenga presionado **en el instante del arranque**
(power-on, reset, o wake por temporizador):

| Sostenido | Modo |
|---|---|
| No presionado | Ciclo normal: mide, envía, duerme |
| 3-8 s | Calibración: 60 s de distancia cruda por serial a 2 Hz |
| Más de 8 s | Portal de configuración WiFi/Grafana (`EggBasket-Setup`) |

El LED da feedback de en qué modo se entró — ver `docs/setup-tutorial.md`
para la tabla completa de patrones. Si no hay ninguna configuración WiFi
guardada (equipo recién flasheado), entra directo al portal sin necesidad de
sostener el botón.

## Notas de la corona ToF / cono del sensor

El VL53L0X del TOF200C tiene un cono fijo de 25° y no admite ROI. (Con un
VL53L1X el cono es de 27° y el receptor admite ROI reducido hasta 15° con
4×4 SPADs.) El ángulo físico de montaje se ajusta con la bisagra de
fricción del `pod` (`cad/sensor_head.scad` + `cad/rim_mount.scad`), no por
software. Los detalles de por qué el rango útil es el que calcula
`lib/geometry.scad` están en
`docs/superpowers/specs/2026-09-04-egg-basket-monitor-design.md` y en
`docs/superpowers/specs/2026-09-18-cad-rim-mount-redesign-design.md`.

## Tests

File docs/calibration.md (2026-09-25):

# Calibración del ángulo del sensor

El VL53L0X mide en diagonal a través de la canasta (ver
`docs/superpowers/specs/2026-09-04-egg-basket-monitor-design.md`, sección "El
cono del emisor decide dónde se monta"). El ángulo correcto no es una
preferencia: la geometría de tu canasta específica fija una ventana válida
(la calcula `lib/geometry.scad` al compilar; con las cotas actuales del
repo es 7.8°-22° desde la vertical).

Desde el rediseño de 2026-09-18
(`docs/superpowers/specs/2026-09-18-cad-rim-mount-redesign-design.md`), la
bisagra del `pod` es de **fricción pura, sin detentes**: se afloja el
`knob`, se gira el `pod` a mano a cualquier ángulo dentro del rango válido,
y se aprieta. Esto hace que este modo de calibración sea más importante que
antes, no menos: no hay una posición "de fábrica" a la que volver, así que
es la única forma de confirmar que el ángulo elegido a ojo es realmente
bueno.

## Cuándo usarlo

- Primera vez que armás la cabeza del sensor sobre la canasta real.
- Cada vez que se afloja el pivote de fricción por cualquier motivo (limpiar
  la canasta, un golpe, etc.): al no haber detentes, el ángulo no vuelve solo
  a su posición anterior.
- Después de imprimir un `pod`/`mount` con distinto `pod_arm`, `pod_reach` o
  `pivot_drop` en `cad/params.scad`.
- Si las lecturas en Grafana muestran `stddev` alto de forma sostenida (ver
  más abajo qué significa eso).

## Cómo entrar

**Automático con la PC:** con la placa conectada por USB y el monitor serie
abierto (`pio device monitor` o el enchufe de PlatformIO en VS Code), cada
arranque entra solo a este modo, sin tocar ningún botón. Si el monitor se
abre después, alcanza con un RESET. Mientras el monitor siga abierto, al
terminar los 60 s reinicia y vuelve a entrar, así que la lectura sigue de
corrido. Para ver por serial el ciclo normal (sensor, WiFi y envío a
Grafana), poner `AUTO_CALIBRATION_ON_SERIAL` a `0` en
`firmware/include/config.h`. En batería o con un cargador no cambia nada.

**Con el botón:** sostener BOOT entre 3 y 8 segundos al arrancar (power-on,
reset, o reconectando la batería); ver `docs/setup-tutorial.md`, sección 6.
El LED confirma con dos parpadeos verdes en los dos casos.

## Qué hace

Durante 60 segundos, el firmware imprime por serial (115200 baudios) una
lectura cruda del VL53L0X a 2 Hz, sin mediana ni filtrado:

```
distancia_mm=412 status=11
distancia_mm=409 status=11
distancia_mm=8190 status=4 (invalida)
...
```

`status` es el estado crudo de la medición del VL53L0X (bits 6..3 del
registro `RESULT_RANGE_STATUS`): `11` = medición completa y válida; otros
valores indican señal débil (`4`, `5`), sigma alto (`7`), fase fuera de
límites (`6`, `9`) o fallo de hardware (`1`-`3`). Las líneas marcadas
`(invalida)` son las que el ciclo normal descarta, incluido 8190/8191 mm,
que es "sin objetivo en rango".

## Cómo elegir el ángulo

1. Con la canasta **vacía**, aflojá el `knob` lo justo para poder girar el
   `pod` a mano (sin que se caiga solo), no lo saques del todo.
2. Entrá a modo calibración y mirá los valores mientras movés el `pod`
   lentamente dentro del rango válido que imprime `python cad/build.py`
   (`Rango util de la bisagra de friccion: ...` en el reporte de
   `lib/geometry.scad`).
3. Apretá el `knob` a mano en el punto donde:
   - La lectura es **estable** (los valores no saltan más de unos pocos mm
     entre sí).
   - `status=0` en la gran mayoría de las lecturas.
   - La distancia con la canasta vacía y con la canasta llena da un rango
     amplio (más recorrido = más resolución para estimar nivel).
4. Repetí el paso 2 una vez apretado, para confirmar que apretar el `knob`
   no corrió el ángulo (la fricción a veces desplaza un par de grados al
   tensar).
5. El ángulo nominal de diseño es ~15° (centro del rango válido), con
   ~466 mm vacía / ~362 mm llena (~103 mm de recorrido) — ver el reporte de
   `python cad/build.py` para las cifras exactas con tus cotas. Si tu
   canasta real da números muy distintos, revisá que las medidas en
   `cad/params.scad` coincidan con la canasta que tenés.

## Qué significa `stddev` alto en producción

Una vez calibrado y en operación normal, cada envío a Grafana incluye
`stddev` (desviación estándar de las 20 lecturas de ese ciclo) y `valid`
(cuántas de esas 20 fueron válidas). Si `stddev` sube de forma sostenida en
el dashboard:

- El ángulo se corrió (un huevo golpeó el pod, se aflojó el knob, etc.) — más
  probable ahora que la bisagra es de fricción y no tiene topes fijos.
- Volvé a este modo de calibración para verificar y, si hace falta, ajustar
  el ángulo sin reimprimir nada.

Esto es intencional por diseño: `stddev` y `valid` son la señal de que el
ángulo está mal *antes* de que los datos de nivel se vuelvan basura, no un
detalle de diagnóstico secundario.

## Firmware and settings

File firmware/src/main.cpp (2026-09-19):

#include <Arduino.h>
#include <WiFi.h>

#include "boot_mode.h"
#include "config.h"
#include "portal.h"
#include "power.h"
#include "sensor.h"
#include "settings.h"
#include "telemetry.h"

namespace {

void runNormalCycle() {
    Serial.println("\n=== Ciclo normal ===");

    SensorReading reading = sensor::readDistance();
    if (reading.sensorOk) {
        Serial.printf("Sensor: distancia=%u mm  stddev=%.1f  validas=%d/%d\n",
                      reading.medianDistanceMm, reading.stddevMm, reading.validCount,
                      SENSOR_SAMPLE_COUNT);
    } else {
        Serial.println("Sensor: fallo de lectura (revisar cableado I2C, ver docs/wiring.md)");
    }

    float batteryVolts = power::readBatteryVolts();
    uint32_t batteryMv = static_cast<uint32_t>(batteryVolts * 1000.0f);
    Serial.printf("Bateria: %.2f V\n", batteryVolts);

    if (batteryVolts < BATTERY_CUTOFF_VOLTS) {
        Serial.println("Bateria por debajo del corte: durmiendo indefinidamente");
        Serial.flush();
        power::showLed(LedPattern::BatteryCutoff);
        power::deepSleepIndefinitely();
        // no retorna
    }

    DeviceSettings cfg = settings::load();

    Serial.printf("Conectando a WiFi '%s'...\n", cfg.wifiSsid.c_str());
    WiFi.mode(WIFI_STA);
    WiFi.begin(cfg.wifiSsid.c_str(), cfg.wifiPassword.c_str());
    uint32_t start = millis();
    while (WiFi.status() != WL_CONNECTED && millis() - start < WIFI_CONNECT_TIMEOUT_MS) {
        delay(100);
    }

    bool posted = false;
    if (WiFi.status() == WL_CONNECTED) {
        Serial.printf("WiFi conectado: IP=%s  RSSI=%ddBm\n", WiFi.localIP().toString().c_str(),
                      WiFi.RSSI());
        posted = telemetry::sendReading(cfg, reading, batteryMv, WiFi.RSSI());
    } else {
        // Sin conexión: igual encolamos la muestra pasando rssi=0. El envío
        // en sí solo puede fallar (no hay red), pero sendReading se encarga
        // de guardarla en el buffer de reintento.
        Serial.println("WiFi: no conecto dentro del timeout, se guarda la muestra para reintentar");
        telemetry::sendReading(cfg, reading, batteryMv, 0);
    }

    Serial.println(posted ? "POST a Grafana Cloud: OK"
                           : "POST a Grafana Cloud: FALLO (muestra guardada para el proximo ciclo)");

    power::showLed(posted ? LedPattern::PostSuccess : LedPattern::PostFailed);

    WiFi.disconnect(true);
    Serial.printf("Durmiendo %u minutos...\n", cfg.sleepMinutes);
    Serial.flush();
    power::deepSleepFor(cfg.sleepMinutes);
    // no retorna
}

}  // namespace

void setup() {
    Serial.begin(115200);
    power::initLed();

    DeviceSettings existing = settings::load();
    BootMode mode = boot_mode::detect(existing.wifiSsid.length() > 0);

    switch (mode) {
        case BootMode::Config: {
            power::showLed(LedPattern::ConfigEntered);
            bool saved = portal::runConfigPortal();
            if (saved) {
                ESP.restart();
            }
            // Timeout sin guardar: si ya había config previa, se reintenta
            // el ciclo normal; si no había ninguna, se vuelve a levantar el
            // portal en el próximo arranque.
            if (existing.isComplete()) {
                runNormalCycle();
            } else {
                power::deepSleepFor(1);  // reintenta el portal pronto
            }
            break;
        }
        case BootMode::Calibration: {
            power::showLed(LedPattern::CalibrationEntered);
            Serial.println("Modo calibracion: distancia cruda durante 60s a 2Hz");
            sensor::runCalibrationStream(60000);
            ESP.restart();
            break;
        }
        case BootMode::Normal:
        default:
            runNormalCycle();
            break;
    }
}

void loop() {
    // Todo el trabajo pasa en setup(); el dispositivo duerme antes de llegar
    // aca. loop() no debería ejecutarse nunca.
}

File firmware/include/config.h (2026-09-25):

#pragma once

#include <Arduino.h>

// ---------------------------------------------------------------------------
// Pinout — ver docs/wiring.md para el diagrama completo.
//
// En el ESP32-C3 SuperMini el número serigrafiado junto a cada pin ES el
// número de GPIO (el pin marcado "4" en la placa es GPIO4): no hay alias
// tipo D0/D1 como en otras placas Arduino/ESP8266. Por eso cada constante de
// abajo lleva el número tal cual aparece impreso en la placa (GPIOx_...) y
// además un alias con el nombre funcional (PIN_...) que es el que usa el
// resto del firmware.
//
// Se evita el bus I2C por defecto del C3 (GPIO8/GPIO9) porque GPIO8 es el
// LED RGB integrado y GPIO9 es el botón BOOT; el I2C se remapea a GPIO4/5.
// ---------------------------------------------------------------------------
constexpr int GPIO4_SDA = 4;          // marcado "4" en la placa
constexpr int GPIO5_SCL = 5;          // marcado "5" en la placa
constexpr int GPIO6_XSHUT = 6;        // marcado "6" en la placa
constexpr int GPIO3_BATTERY_ADC = 3;  // marcado "3" en la placa
constexpr int GPIO9_BOOT = 9;         // marcado "9" en la placa; boton BOOT integrado
constexpr int GPIO8_LED = 8;          // marcado "8" en la placa; LED RGB integrado

constexpr int PIN_I2C_SDA = GPIO4_SDA;
constexpr int PIN_I2C_SCL = GPIO5_SCL;
constexpr int PIN_XSHUT = GPIO6_XSHUT;
constexpr int PIN_BATTERY_ADC = GPIO3_BATTERY_ADC;
constexpr int PIN_BOOT_BUTTON = GPIO9_BOOT;  // activo en bajo, pull-up interno
constexpr int PIN_STATUS_LED = GPIO8_LED;

// La mayoría de las placas "C3 SuperMini" traen un WS2812 direccionable en
// GPIO8. Algunas variantes traen en cambio un LED simple de un solo color.
// Si el LED no enciende con colores o queda siempre apagado, cambiar a 0 y
// power.cpp usa digitalWrite/parpadeo simple en su lugar.
#define STATUS_LED_IS_NEOPIXEL 1

// ---------------------------------------------------------------------------
// Umbrales de arranque
// ---------------------------------------------------------------------------
constexpr uint32_t BOOT_DECISION_WINDOW_MS = 8500;   // ventana total de lectura del botón
constexpr uint32_t CALIBRATION_HOLD_MIN_MS = 3000;   // 3-8s => modo calibración
constexpr uint32_t CALIBRATION_HOLD_MAX_MS = 8000;
constexpr uint32_t CONFIG_HOLD_MIN_MS = 8000;        // >8s => modo config

// Con un monitor serie abierto por USB al arrancar, entra solo a modo
// calibración, sin sostener BOOT. En batería no cuesta nada (sin host USB se
// descarta en ~20 ms). Poner a 0 para ver por serial el ciclo normal.
#define AUTO_CALIBRATION_ON_SERIAL 1
// Cuánto esperar a que el monitor se (re)conecte tras un reset o un flasheo,
// sólo cuando hay una PC conectada por USB.
constexpr uint32_t SERIAL_MONITOR_WAIT_MS = 3000;

// ---------------------------------------------------------------------------
// Portal de configuración (WiFiManager)
// ---------------------------------------------------------------------------
constexpr const char *AP_SSID = "EggBasket-Setup";
constexpr const char *AP_PASSWORD = "eggbasket2026"; // cambiar antes de flashear si se desea
constexpr uint32_t PORTAL_TIMEOUT_S = 5 * 60;        // 5 minutos sin actividad

// ---------------------------------------------------------------------------
// Medición
// ---------------------------------------------------------------------------
// El VL53L0X (módulo TOF200C) no tiene ROI: el cono de 25° es fijo.
constexpr int SENSOR_SAMPLE_COUNT = 20;

// ---------------------------------------------------------------------------
// Batería
// ---------------------------------------------------------------------------
// 2.0 porque el divisor usa dos resistencias IGUALES entre si (R1=R2): el
// punto medio siempre queda a mitad de camino sin importar el valor absoluto
// (1M/1M, 100k/100k, etc. dan el mismo 2.0). Solo cambia si R1 != R2.
constexpr float BATTERY_DIVIDER_RATIO = 2.0f;
constexpr float BATTERY_CUTOFF_VOLTS = 3.3f;

// ---------------------------------------------------------------------------
// Config por defecto (usada solo si no hay nada guardado en NVS)
// ---------------------------------------------------------------------------
constexpr const char *DEFAULT_DEVICE_TAG = "cocina";
constexpr uint32_t DEFAULT_SLEEP_MINUTES = 60;
constexpr uint32_t MIN_SLEEP_MINUTES = 5;
constexpr uint32_t MAX_SLEEP_MINUTES = 1440;

constexpr uint32_t WIFI_CONNECT_TIMEOUT_MS = 15000;
constexpr uint32_t HTTP_TIMEOUT_MS = 10000;

// Ruta fija del endpoint de compatibilidad Influx de Grafana Cloud. Es igual
// para cualquier cuenta/region: lo unico que cambia entre usuarios es el
// host. telemetry.cpp la agrega automaticamente a lo que se haya guardado en
// el portal, aunque el usuario haya pegado solo el host (con o sin path,
// con o sin "https://") — asi un error de tipeo como pegar la URL de
// Prometheus sin esta ruta ya no rompe el envio.
constexpr const char *INFLUX_WRITE_PATH = "/api/v1/push/influx/write";
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

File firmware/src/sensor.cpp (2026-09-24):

#include "sensor.h"

#include <VL53L0X.h>
#include <Wire.h>
#include <math.h>

#include "config.h"

namespace {

// El módulo instalado es un TOF200C, que lleva un VL53L0X (no un VL53L1X):
// los dos contestan en 0x29 pero el VL53L0X usa direcciones de registro de
// 8 bits y el VL53L1X de 16, así que la librería del VL53L1X nunca pasaba de
// init(). Ver docs/wiring.md.
VL53L0X vl53;

// Estado de medición del VL53L0X (bits 6..3 de RESULT_RANGE_STATUS) que
// corresponde a "medición completa"; el resto son fallos de señal, sigma,
// fase o hardware.
constexpr uint8_t RANGE_STATUS_VALID = 11;

// 8190/8191 mm es lo que devuelve el VL53L0X cuando no hay objetivo en rango.
constexpr uint16_t RANGE_OUT_OF_RANGE_MM = 8190;

void powerOn() {
    // XSHUT se suelta en vez de forzarlo a 3.3 V: el módulo lo trae con
    // pull-up a su propio regulador. El pull-up interno cubre módulos sin él.
    pinMode(PIN_XSHUT, INPUT_PULLUP);
    // t_BOOT del VL53L0X es 1.2 ms como máximo, pero no tiene registro de
    // "arrancado" que consultar; se deja margen de sobra.
    delay(50);
}

void powerOff() {
    pinMode(PIN_XSHUT, OUTPUT);
    digitalWrite(PIN_XSHUT, LOW);
}

bool initSensor() {
    Wire.begin(PIN_I2C_SDA, PIN_I2C_SCL);
    vl53.setTimeout(500);
    if (!vl53.init()) {
        return false;
    }
    // 50 ms por medición en vez de los ~33 ms por defecto: menos ruido, y el
    // rango real de esta instalación (345-450mm) no necesita el perfil de
    // largo alcance.
    vl53.setMeasurementTimingBudget(50000);
    vl53.startContinuous();
    return true;
}

// Como readRangeContinuousMillimeters() de la librería, pero devuelve además
// el estado de la medición, que la librería descarta. false = timeout.
bool readMeasurement(uint16_t &mm, uint8_t &status) {
    uint32_t start = millis();
    while ((vl53.readReg(VL53L0X::RESULT_INTERRUPT_STATUS) & 0x07) == 0) {
        if (millis() - start > vl53.getTimeout()) {
            return false;
        }
    }
    status = (vl53.readReg(VL53L0X::RESULT_RANGE_STATUS) >> 3) & 0x0F;
    mm = vl53.readReg16Bit(VL53L0X::RESULT_RANGE_STATUS + 10);
    vl53.writeReg(VL53L0X::SYSTEM_INTERRUPT_CLEAR, 0x01);
    return true;
}

bool isValid(uint16_t mm, uint8_t status) {
    return status == RANGE_STATUS_VALID && mm < RANGE_OUT_OF_RANGE_MM;
}

}  // namespace

namespace sensor {

SensorReading readDistance() {
    SensorReading result;
    powerOn();

    if (!initSensor()) {
        powerOff();
        return result;
    }

    uint16_t samples[SENSOR_SAMPLE_COUNT];
    int validCount = 0;

    for (int i = 0; i < SENSOR_SAMPLE_COUNT; i++) {
        uint16_t mm;
        uint8_t status;
        if (readMeasurement(mm, status) && isValid(mm, status)) {
            samples[validCount++] = mm;
        }
        delay(10);
    }

    vl53.stopContinuous();
    powerOff();

    if (validCount == 0) {
        result.sensorOk = false;
        return result;
    }

    // Mediana
    for (int i = 0; i < validCount - 1; i++) {
        for (int j = i + 1; j < validCount; j++) {
            if (samples[j] < samples[i]) {
                uint16_t tmp = samples[i];
                samples[i] = samples[j];
                samples[j] = tmp;
            }
        }
    }
    uint16_t median = samples[validCount / 2];

    // Desviación estándar
    float mean = 0;
    for (int i = 0; i < validCount; i++) mean += samples[i];
    mean /= validCount;
    float variance = 0;
    for (int i = 0; i < validCount; i++) {
        float d = samples[i] - mean;
        variance += d * d;
    }
    variance /= validCount;

    result.medianDistanceMm = median;
    result.stddevMm = sqrtf(variance);
    result.validCount = validCount;
    result.sensorOk = true;
    return result;
}

void runCalibrationStream(uint32_t durationMs) {
    powerOn();
    if (!initSensor()) {
        Serial.println("VL53L0X: fallo de init, revisar cableado (ver docs/wiring.md)");
        powerOff();
        return;
    }

    uint32_t start = millis();
    while (millis() - start < durationMs) {
        uint16_t mm;
        uint8_t status;
        if (readMeasurement(mm, status)) {
            Serial.printf("distancia_mm=%u status=%u%s\n", mm, status,
                          isValid(mm, status) ? "" : " (invalida)");
        } else {
            Serial.println("timeout leyendo el sensor");
        }
        delay(500);  // 2 Hz
    }

    vl53.stopContinuous();
    powerOff();
}

}  // namespace sensor

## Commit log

2026-09-04 docs: diseño del monitor de nivel de canasta de huevos
    Spec de arquitectura: VL53L1X en montaje diagonal sobre el borde de la
    canasta, ESP32-C3 SuperMini con 18650, POST Influx directo a Grafana
    Cloud y dos alertas a Telegram (nivel bajo y sensor caído).
    La calibración distancia→nivel vive en las queries de Grafana, no en el
    firmware, para poder reajustarla sin desmontar ni reflashear.
2026-09-04 cad: cabeza del sensor parametrica con articulacion Hirth
    Modelo OpenSCAD de la pieza que se cuelga del borde de la canasta. Todas
    las cotas viven en params.scad; cambiar de canasta es cambiar
    rim_thickness y nada mas.
    Cuatro piezas, ninguna necesita soportes: mordaza (prisma puro, se
    imprime de canto), placa de bisagra y pod (planos, dientes hacia arriba)
    y pomo.
    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
    [params.scad, sensor_head.scad]
2026-09-04 cad: ventana optica correcta y nervios en el pod; spec al dia
    La ventana era de 12 mm en un bolsillo de PCB de 11.8 mm de alto, o sea
    que se lo comia entero y dejaba el modulo sin apoyo arriba y abajo. Se
    baja a 8 mm, que es lo que de verdad hace falta para que el cono de 27
    grados pase los 4 mm de material que quedan por delante del PCB.
    El brazo del pod sujetaba en voladizo una pared de 18 mm con solo 3.2 mm
    de espesor. Se anaden dos nervios en los extremos, por detras de la
    pared, donde no invaden ni el bolsillo ni el cono optico.
    El spec seguia describiendo el plan de CAD anterior a tener las medidas
    de la canasta. Se actualiza con las cotas reales, con el hallazgo de que
    el cono fijo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
    [params.scad, sensor_head.scad]
2026-09-04 cad: caja de electronica y coronas Hirth mas pequenas
    Dos criticas del usuario, las dos justas.
    (a) No habia sitio para la bateria ni la electronica. Se anade
    cad/electronics_box.scad con box, lid y hook: 18650 de pie, TP4056 y
    ESP32-C3 tumbados contra el fondo con los dos USB-C saliendo por el
    mismo costado. 55x81x24 mm.
    La caja cuelga POR FUERA del borde. Esto invierte la decision del spec
    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
    [electronics_box.scad, params.scad, sensor_head.scad]
2026-09-07 docs: lista de materiales consolidada
    Recoge lo que ya tiene el usuario, lo que hay que comprar y la tornilleria
    exacta que calculan los modelos al compilar.
    Caen dos items de la primera version:
    - imanes de neodimio: la caja cuelga ya del borde con su gancho
    - miniprotoboard: mide 47x35 mm y el vano de la caja tiene 29 de ancho.
    Las dos resistencias del divisor se sueldan en linea sobre un Dupont.
2026-09-07 cad: eliminar todos los tornillos autorroscantes
    El usuario tiene M2/M3/M4 de metrica normal a millares y ningun
    autorroscante. Los tres sitios que roscaban en el plastico pasan a
    tornillo pasante contra tuerca hexagonal embutida en la pieza.
    - rim_hook: tuerca cautiva en la cara exterior del saliente de apriete.
    Afecta a la mordaza del sensor y al gancho de la caja a la vez.
    - pod: los pilotos M2 de Ø2.1 pasan a pasantes Ø2.3; la tuerca va suelta
    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
    [electronics_box.scad, params.scad, sensor_head.scad]
2026-09-08 docs: agrega README con imagenes de las piezas
    README raiz (no existia): resumen del proyecto, hardware, imagenes
    de las piezas impresas y enlaces al BOM. Agrega renders de knob y
    hook para completar la cobertura de imagenes.
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2026-09-18 docs+firmware: aclarar bus I2C y numeracion de pines en el diagrama y el codigo
    El diagrama anterior no alineaba las lineas de SDA/SCL con las filas
    correctas del modulo VL53L1X (quedaban apuntando a la fila equivocada).
    Se realinean todas las señales fila por fila entre el ESP32-C3 y el
    VL53L1X, se agrega un recuadro punteado "Bus I2C" y se aclara que ese
    bus es bidireccional (SCL lo genera el ESP32 como maestro).
    Se agrega tambien una aclaracion explicita, en el diagrama y en
    wiring.md, de que el numero GPIOx coincide con el numero serigrafiado
    en la placa del C3 SuperMini (no hay alias tipo D0/D1). En
    config.h cada pin ahora tiene dos constantes: GPIOx_NOMBRE con el
    numero tal como apar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
    [config.h]
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2026-09-18 docs: spec de rediseño CAD (mount unificado, bisagra de friccion, cotas TOF200C)
    Fusiona clamp+hook en una sola pieza, reemplaza la articulacion Hirth por un
    pivote de friccion y corrige las cotas del sensor TOF200C real. La caja de
    electronica ya impresa queda intacta.
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2026-09-18 cad: cotas reales del TOF200C y parametros de la bisagra de friccion
    geometry.scad pasa de listar detentes discretos a validar un rango continuo
    de angulos, porque la bisagra de friccion no tiene posiciones fijas.
    [params.scad]
2026-09-18 cad: pod con oreja de friccion, elimina clamp/plate/hirth de sensor_head
    [sensor_head.scad]
2026-09-18 cad: nueva pieza mount, fusiona clamp+hook en un solo punto de apriete
    [rim_mount.scad]
2026-09-18 cad: quita hook de electronics_box, se muda a rim_mount.scad
    box/lid quedan bit a bit identicas (77.4x81x24.4mm, hueco 70mm). Los asserts
    que validaban la geometria del gancho se mudan a rim_mount.scad, que es
    donde ahora vive esa pieza.
    [electronics_box.scad]
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2026-09-18 cad: corrige signo de rotacion del pod en assembly()
    Con rotate(90,0,0) la oreja del pod caia en el mismo tramo de Y que la del
    mount (colision) en vez de extenderse hacia afuera donde va el pomo.
    [sensor_head.scad]
2026-09-18 cad: restaura el echo de tornilleria M2 del sensor, se habia perdido al reescribir sensor_head
    [sensor_head.scad]
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2026-09-18 cad: corrige direccion de apuntado invertida en la vista previa del pod
    La auditoria post-implementacion encontro que rotate([-90,0,0]) evitaba la
    colision de orejas pero invertia la direccion de apuntado del sensor en
    assembly() (apuntaba hacia el borde en vez de hacia el fondo). La rotacion
    correcta para apuntar es +90; el fix real es un mirror([0,0,1]) dentro de
    pod() para que esa MISMA rotacion +90 tambien separe las orejas sin colision.
    De paso: limpia parametros muertos en params.scad que dejo la fusion
    clamp+hook (box_hook_w/in/pad, clamp_grip_out, hinge_washer_d), corrige
    comentarios que quedaron corridos, y actualiza docs/calibration.md,
    docs/wiring.md y docs/bom.md que seguian des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
    [params.scad, sensor_head.scad]
2026-09-19 cad: tuerca M3 cautiva en la oreja del pivote del mount
    La oreja del pivote solo tenia un agujero pasante liso; la unica tuerca de
    todo el eje quedaba en el pomo, del otro lado del pod. Se agrega una tuerca
    cautiva en el mount (abierta hacia el pod, que la deja atrapada al montarse)
    para que el tornillo de rosca completa ancle ahi y se tense girando el pomo
    del otro extremo.
    hinge_ear_t sube de 5 a 6mm para dejar los 3mm de pared minimos detras de la
    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
    [params.scad, rim_mount.scad, sensor_head.scad]
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2026-09-19 cad: corrige el brazo del mount que tapaba el agujero del pivote
    Bug real (reportado por el usuario tras inspeccionar la pieza): el offset
    del brazo hacia la oreja restaba hinge_arm_t/2 de mas, desplazandolo
    hinge_arm_t/2 hacia la mordaza en vez de coincidir con la oreja. Ese
    desplazamiento hacia que el brazo solido, al unirse, interfiriera con el
    corte del agujero pasante y la tuerca cautiva, dejando la oreja
    practicamente ciega (sin paso para el tornillo).
    Verificado con una sonda axial (interseccion de un cubo delgado centrado en
    el eje del pivote contra mount()): antes del fix daba solido en todo el
    rango; despues da vacio, como corresponde al agujero + tuerca.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
    [rim_mount.scad]
2026-09-19 cad: mueve la tuerca cautiva del pivote a la cara de la mordaza
    A pedido del usuario: la tuerca hexagonal pasa de la cara que mira al pod a
    la cara que mira a la mordaza/borde. Ya no queda atrapada por el pod al
    montarlo (nada la tapa, es un alojamiento abierto), la sujeta el hexagono y
    la presion del tornillo una vez apretado. Actualiza los comentarios de
    params.scad y sensor_head.scad que describian el mecanismo anterior.
    [params.scad, rim_mount.scad, sensor_head.scad]
2026-09-19 firmware: agregar logging por serial al ciclo normal
    El ciclo de medicion normal no imprimia nada por serial (solo el modo
    calibracion lo hacia), asi que no habia forma de confirmar por que un
    POST fallaba sin instrumentar el codigo a mano. Se agrega log de la
    lectura del sensor, bateria, conexion WiFi y el codigo HTTP devuelto
    por Grafana Cloud (con el body de la respuesta si no es 2xx). Se
    agrega Serial.flush() + delay antes de ambos modos de deep sleep para
    que el USB-CDC alcance a transmitir el ultimo log antes de cortar
    la energia.
    Se documenta en setup-tutorial.md el log esperado y como forzar un
    envio inmediato (reset simple, sin necesidad de tocar BOOT).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
    [main.cpp, power.cpp, telemetry.cpp]
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2026-09-25 docs: esquemas de conexionado nuevos y renders del CAD actual
    - wiring-schematic.svg: SuperMini con sus 16 pines en la posición real,
    TOF200C, TP4056, celda y divisor con resistencias; cables ortogonales
    con colores estándar, pines usados/libres y leyenda.
    - power-chain.svg: corrige el divisor, que toma la tensión de OUT+ (la
    celda) y no de la salida del ESP32; tensiones en cada tramo.
    - Renders de OpenSCAD de las piezas actuales (cabeza del sensor, caja,
    conjunto en el borde y las cinco piezas). Se borran las imágenes del
    diseño anterior (Hirth, clamp, hook), que ya no se usaban.
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2026-09-25 firmware: modo calibración automático con el monitor serie abierto
    Si al arrancar hay una PC por USB con un monitor serie leyendo el puerto,
    entra a modo calibración sin sostener BOOT. Usa la detección de HWCDC: sin
    host USB (batería o cargador) se descarta en ~20 ms, así que el ciclo
    normal en batería no cambia; con la PC conectada pero sin monitor espera
    hasta 3 s a que se reconecte tras un reset o un flasheo. El botón BOOT
    sigue igual (3-8 s calibración, >8 s portal) y el primer arranque sin WiFi
    sigue yendo al portal.
    AUTO_CALIBRATION_ON_SERIAL en config.h lo desactiva, para ver por serial
    el ciclo normal.
    [boot_mode.cpp, config.h]
